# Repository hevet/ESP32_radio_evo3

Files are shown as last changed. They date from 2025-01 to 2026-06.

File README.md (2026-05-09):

# ESP32 Web Radio Evo3 (Evolution 3)

<p align="center">
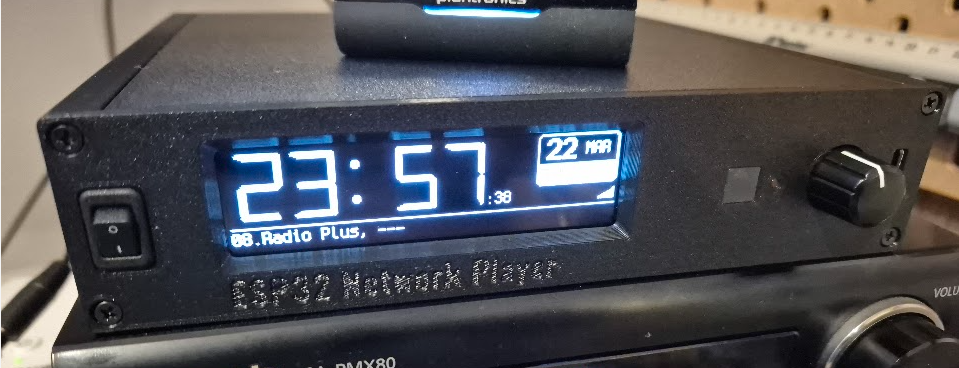
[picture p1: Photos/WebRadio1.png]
ESP32 Radio
  
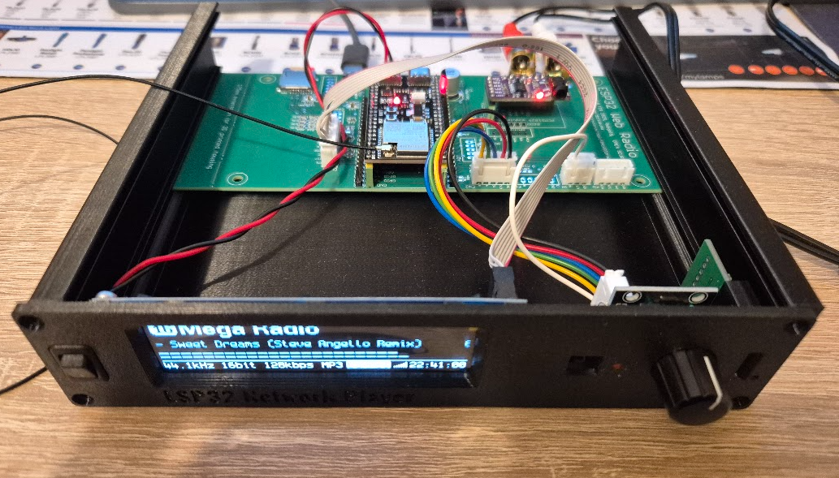
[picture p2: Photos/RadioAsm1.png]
ESP32 Radio
  
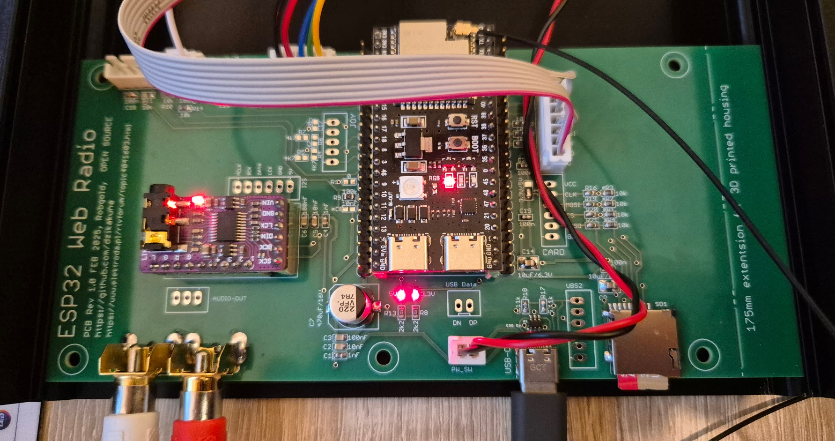
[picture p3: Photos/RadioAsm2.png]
ESP32 Radio
          
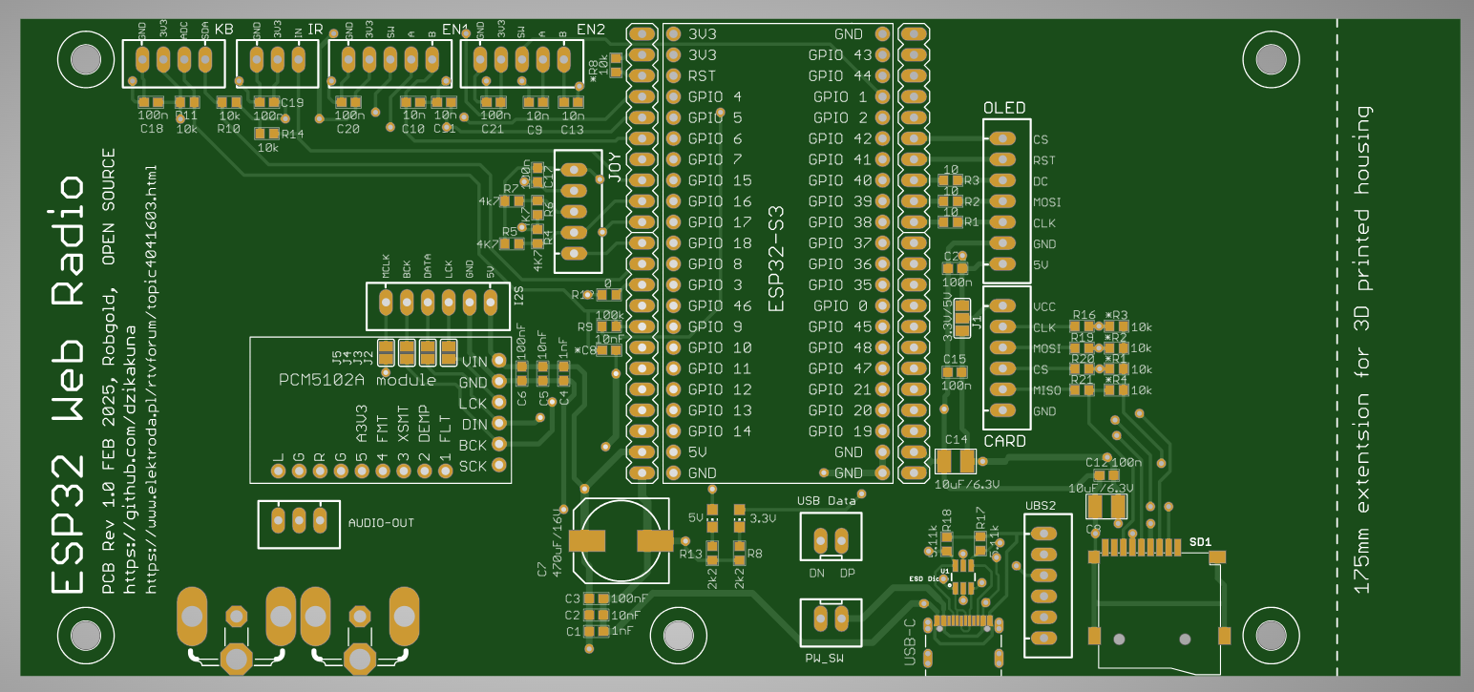
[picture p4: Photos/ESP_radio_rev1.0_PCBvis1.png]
ESP32 Radio
  
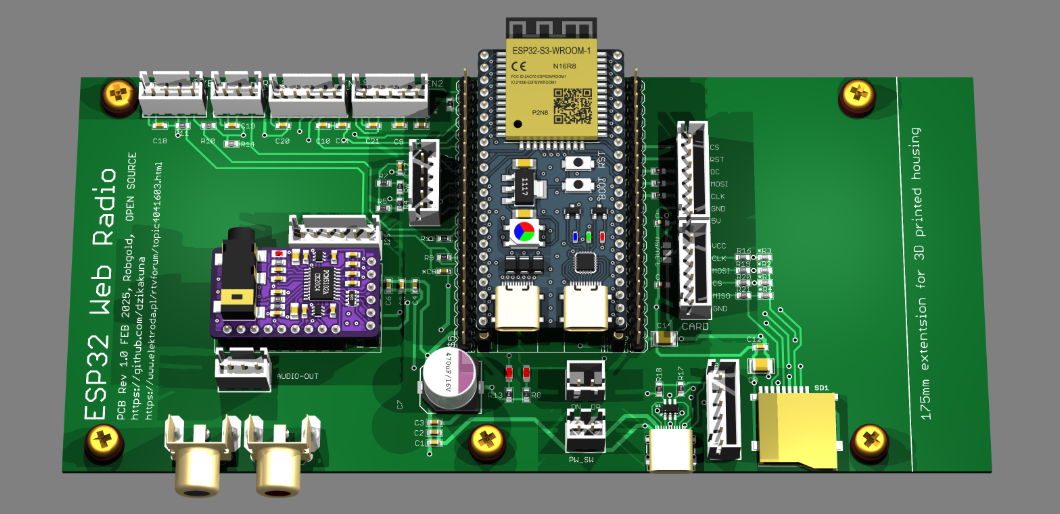
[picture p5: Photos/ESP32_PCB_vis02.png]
  
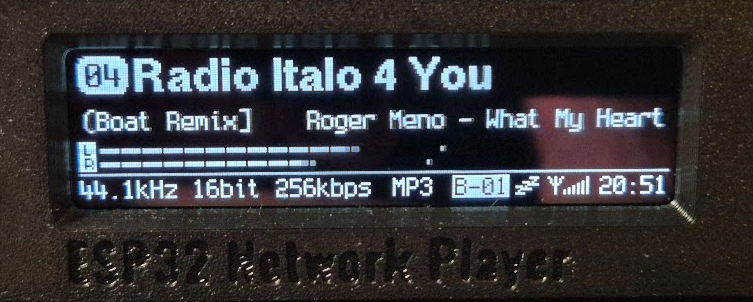
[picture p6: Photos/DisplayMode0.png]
  
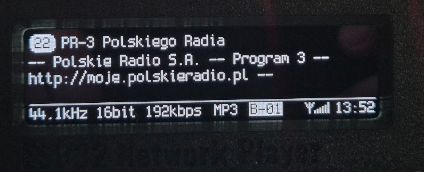
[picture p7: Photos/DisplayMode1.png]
  
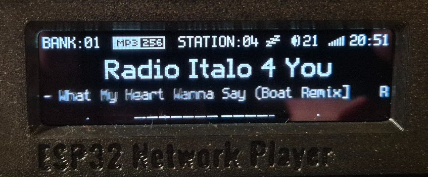
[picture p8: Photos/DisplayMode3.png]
  
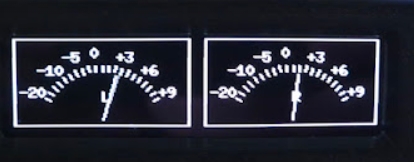
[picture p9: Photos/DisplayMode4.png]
  
</p>

## Overview
This is project of Internet Radio Streamer called "Evo". Hardware was buid using EPS32-S3 and DAC codec PCM5102A. Construction allows to listen varius music station from all around the world.
Working properly with streams coded in MP3, AAC, VORBIS and FLAC up to 2000kbit! Support all operations like volume control, stations changes, memory bank change, power on/off on single rotary 
encoder. Support infrared remote controls working on NEC standars (38kHz) and full control over web page and Android APP.

Many people is mixing wiht others (yoRadio) - Evo is NOT based on yoRadio. Evo Radio streamer was developed entirely in Poland.

Functions:
- Internet radio stream station from bank files (can be stored on SD card/internal LittleFS or downloaded from GitHub)
- I2S simple PCM5102A decoder support
- Full web server integrated for controling from desktop computer or mobile phone
- OLED Display SSD1322, SH1122 (256px x 64px)
- Single rotary encoder operations 
- OTA updates directlly from web page
- SD card /LittleFS content review/upload/download/delete by web page
- VUmeters add as some visualization on OLED
- 16 Banks with 99 station per each Bank support
- Polish fonts add for coorrect display station strings
- 3-point Equalizer
- ADC resistance keyboard support for easy inegration in FM converted tuners
- Power on/off from remote controller
- Sleep timer

## FLAC stations
<p>Smoothjazz.com.pl 16bit 1Mbps and AIDA Radio 24bit 2Mpbs!
<br>
ESP32 Radio
ESP32 Radio
<p>

## Display Modes
ESP32 Radio
ESP32 Radio
ESP32 Radio
ESP32 Radio
ESP32 Radio
ESP32 Radio

## Hardware
- ESP32-S3 dev. module with internal antena or external antena connector
- 256x64 OLED display based on SSD1322 or SH1122 driver IC
- 1x Rotary encoder
- IR 38KHz receiver (Vishay TSOP2238)
- PCB design stored in repository
- Housing avalivle as ready to print STL files
- SD or micro SD card reader (optional)
 
## Software
Project was coded in Arduino but ready main.cpp for Platformio files avalable and also tested

How to compile (Arduino):
- Install fresh Arduino (currently 2.3.6)
- After instalation add ESP32 board package by Espressif (this operation will take some time)
- Install bellow libs inside Arduino (library manager): 
  ESP32-audioI2S, 
  ezButton, 
  U8g2, 
  WiFiManager

Proper version of all libs are placed on top of source code ino file
For Platformio look into src folder -> Platformio folder and Platformio.ini file.

## Software Dependencies
[ESP Espressif 3.3.7 libs]

[3rd-party libs]
- ESP32-audioI2S-master 3.4.4
- U8g2 2.36.5
- ezButton 1.0.4
- WiFiManager 2.0.17
- ESP Async WebServer 3.10.0
- Async TCP 3.4.10

## Web server
Radio has buit in small web server with simple webpage for list stations, bank select, volume control and access to settings menu
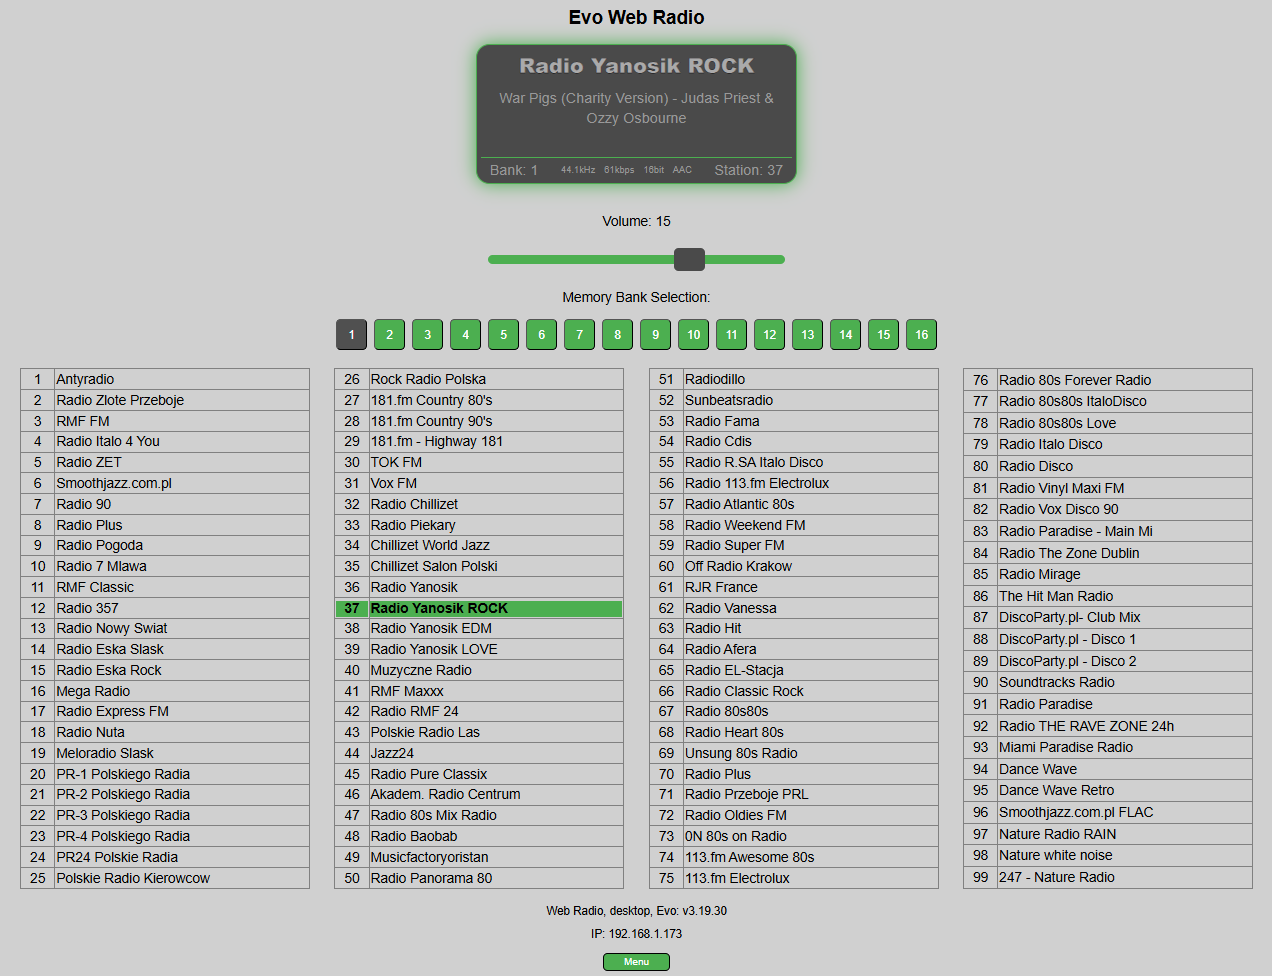
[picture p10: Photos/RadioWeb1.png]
ESP32 Radio


## Radio Browser
The built-in Radio Browser search page allows you to search for various radio stations around the world, and play or test them instantly on Evo Radio.
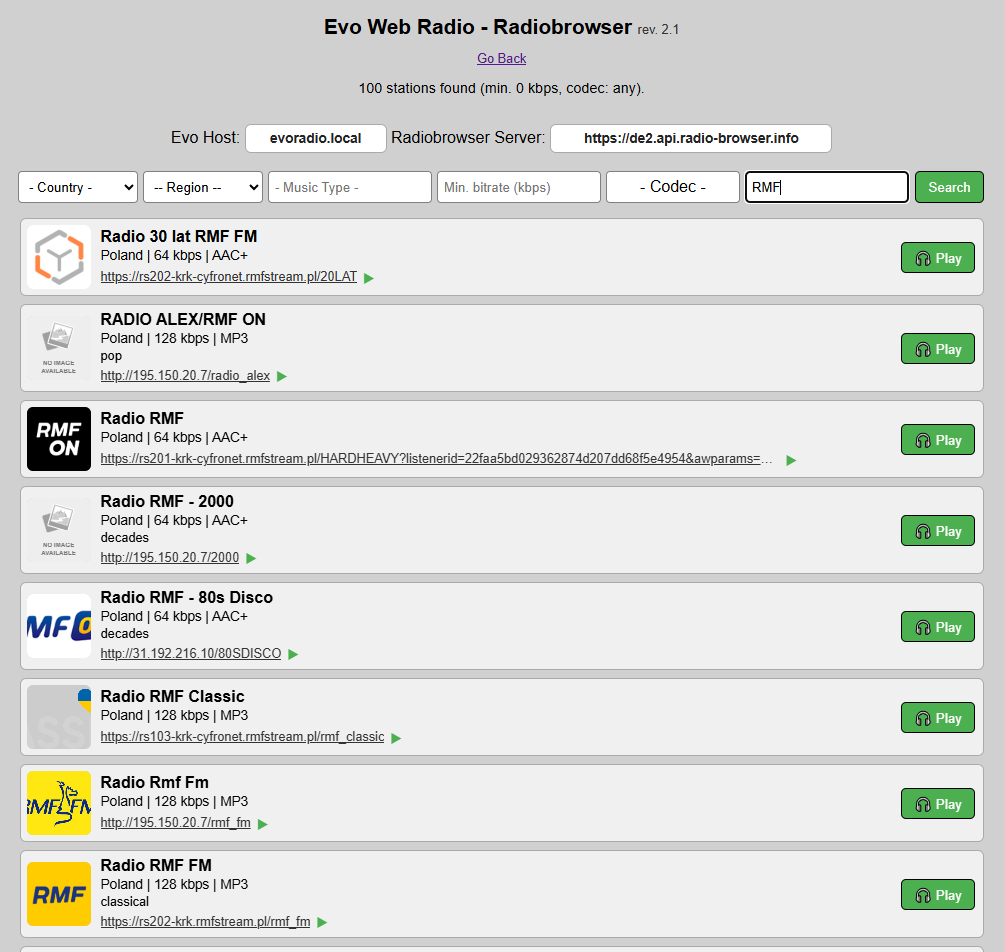
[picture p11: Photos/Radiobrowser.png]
Evo Internet Radio - Radio Browser


## Android APK
There is small Android APK wirtten for this project giving possibily to direct control Evo radio from mobile phone.
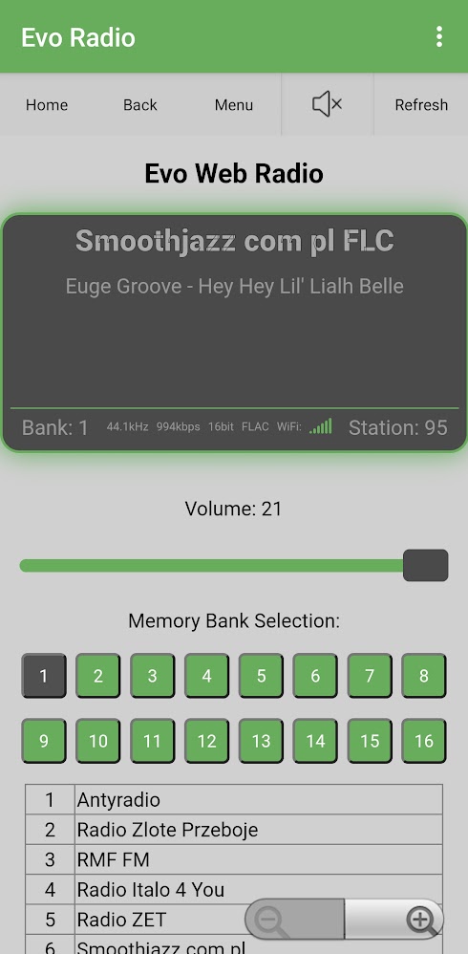
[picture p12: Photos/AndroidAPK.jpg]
Evo Internet Radio - Radio Android APK


There is a pre-coded remote controller RC-406 (Kenwood clone). You can change the settings via a simple web interface or by editing the remote.txt file stored in memory (SD card or internal flash).
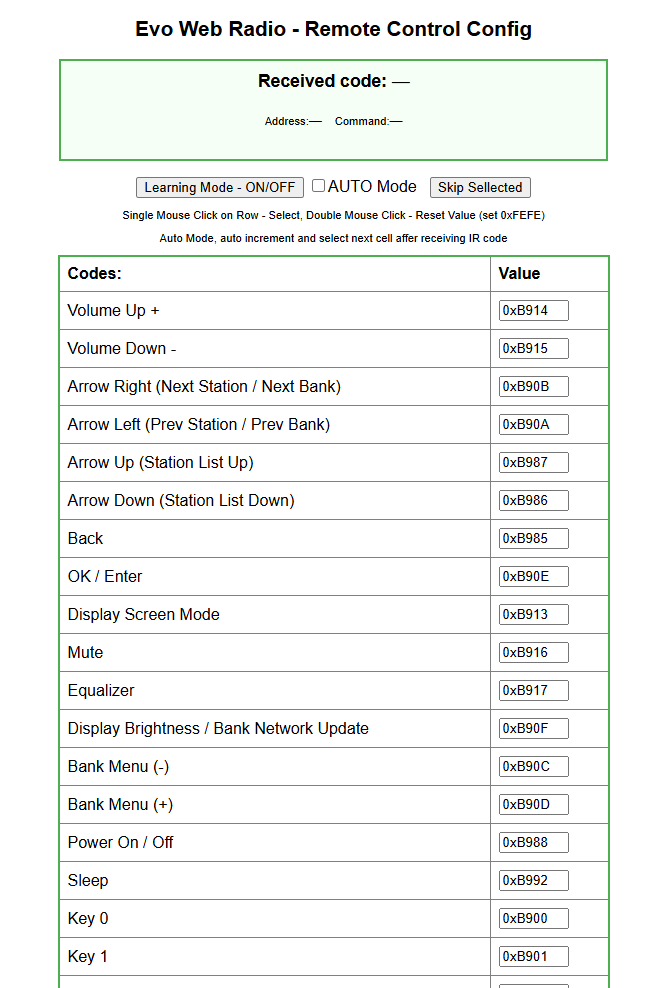
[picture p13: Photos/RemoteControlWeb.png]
Evo Internet Radio - Remote config over web

Key mapping:
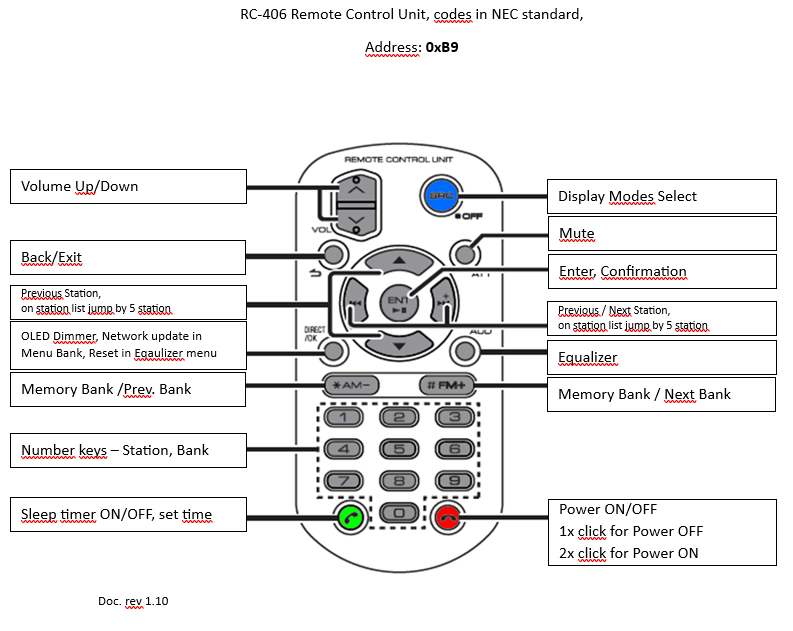
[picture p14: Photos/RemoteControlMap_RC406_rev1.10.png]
Evo Internet Radio - Remote config


## Usage
Minimum radio can be build only with two compoents - ESP32-S3 dev. module and PCM5102A. In this configartion last station, memory bank number and volume will be stored in EEPROM. Control is possible via web page or IR remote control RC-406.
For full experience connect encoder, IR receiver.

NEC standard codes for remote controler are stored in "remote.txt" file. You can learn your IR remote by webpage. 

### Radio Station URLs
The radio streams URL addresses are defined in banks files, each bank is downloaded at first run and stored on SD card as separate txt file: Bank01.txt, Bank02.txt etc.
Each of banks can store 99 station. You can modify the station by changing the URLs in the code. Bank files are stored here:

STATIONS_URL1 "https://raw.githubusercontent.com/dzikakuna/ESP32_radio_streams/main/bank01.txt"
STATIONS_URL2 "https://raw.githubusercontent.com/dzikakuna/ESP32_radio_streams/main/bank02.txt"
STATIONS_URL3 "https://raw.githubusercontent.com/dzikakuna/ESP32_radio_streams/main/bank03.txt"
...
STATIONS_URL16 "https://raw.githubusercontent.com/dzikakuna/ESP32_radio_streams/main/bank16.txt"

## License
This project is open-source and licensed under the [MIT License](https://opensource.org/licenses/MIT). 
Feel free to contribute and improve the code.

MIT License
Copyright (c) 2025 [Grzegorz / Dzikakuna / Robgold ]

Permission is hereby granted, free of charge, to any person obtaining a copy of this software and associated documentation files (the "Software"), to deal in the Software without restriction, including without limitation the rights to use, copy, modify, merge, publish, distribute, sublicense, and/or sell copies of the Software, and to permit persons to whom the Software is furnished to do so, subject to the following conditions:
The above copyright notice and this permission notice shall be included in all copies or substantial portions of the Software.
THE SOFTWARE IS PROVIDED "AS IS", WITHOUT WARRANTY OF ANY KIND, EXPRESS OR IMPLIED, INCLUDING BUT NOT LIMITED TO THE WARRANTIES OF MERCHANTABILITY, FITNESS FOR A PARTICULAR PURPOSE AND NONINFRINGEMENT. IN NO EVENT SHALL THE AUTHORS OR COPYRIGHT HOLDERS BE LIABLE FOR ANY CLAIM, DAMAGES OR OTHER LIABILITY, WHETHER IN AN ACTION OF CONTRACT, TORT OR OTHERWISE, ARISING FROM, OUT OF OR IN CONNECTION WITH THE SOFTWARE OR THE USE OR OTHER DEALINGS IN THE SOFTWARE.

## Others
- This project was inspired by https://github.com/sarunia/ESP32_radio_player_v2
- More informations you can read here: https://www.elektroda.pl/rtvforum/topic4041603.html

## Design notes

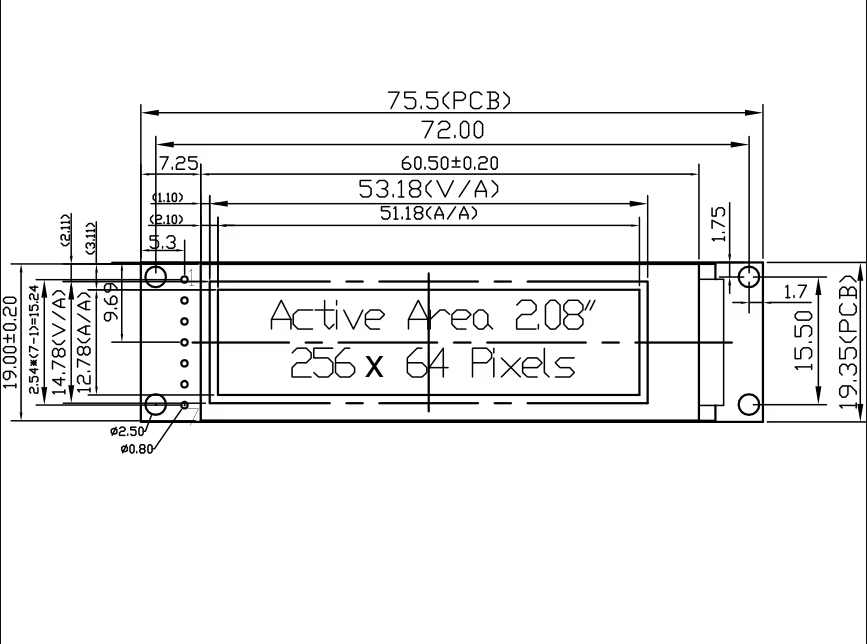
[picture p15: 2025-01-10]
Hardware/Datasheets/2.08 SH1122 OLED display/208-OLED dimensions.png

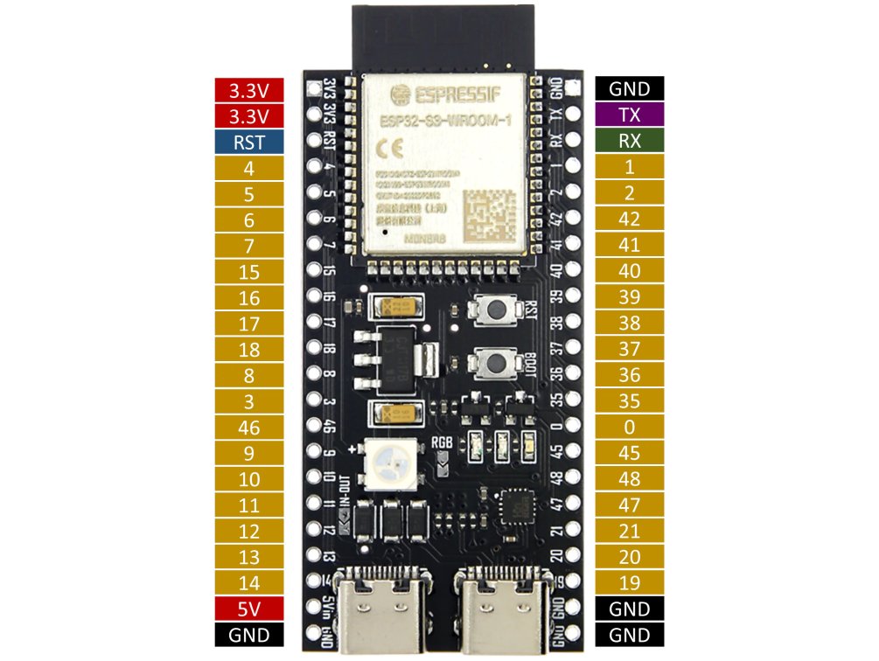
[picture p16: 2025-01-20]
Hardware/Datasheets/ESP/esp32-s3 usbc pinout.jpg

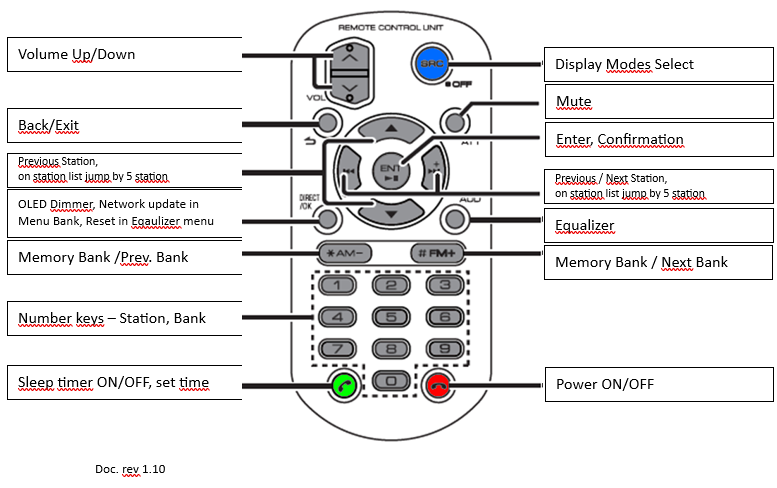
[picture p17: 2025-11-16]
Hardware/RemoteControlMap_RC406_rev1.10.png

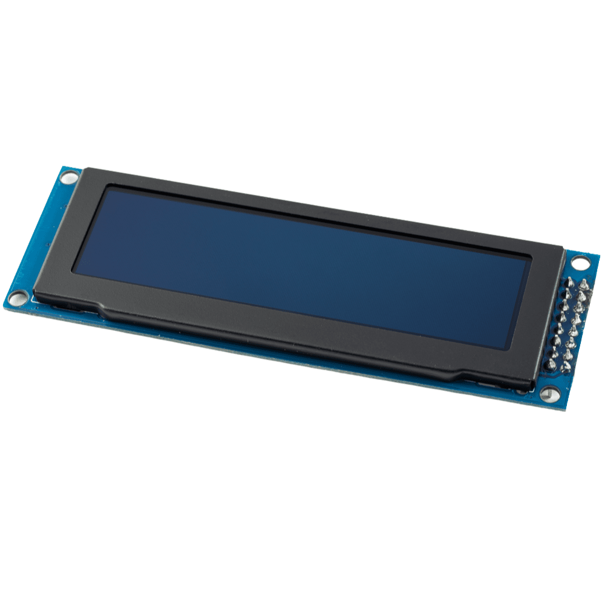
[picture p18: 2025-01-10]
Hardware/Datasheets/3.12 SSD1322 OLED display/312-OLED module photo.png

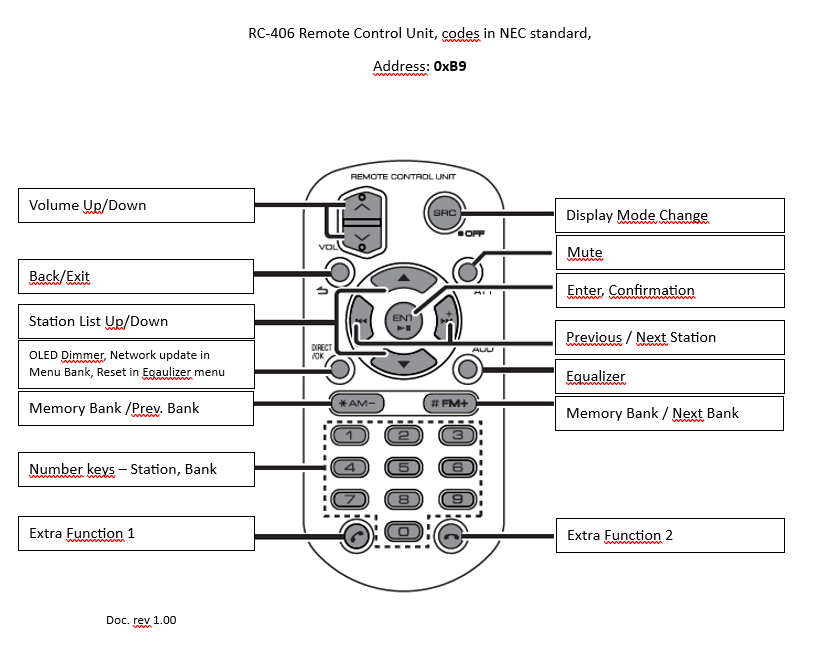
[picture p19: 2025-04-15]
Hardware/RemoteControlMap_RC406_rev1.00.png

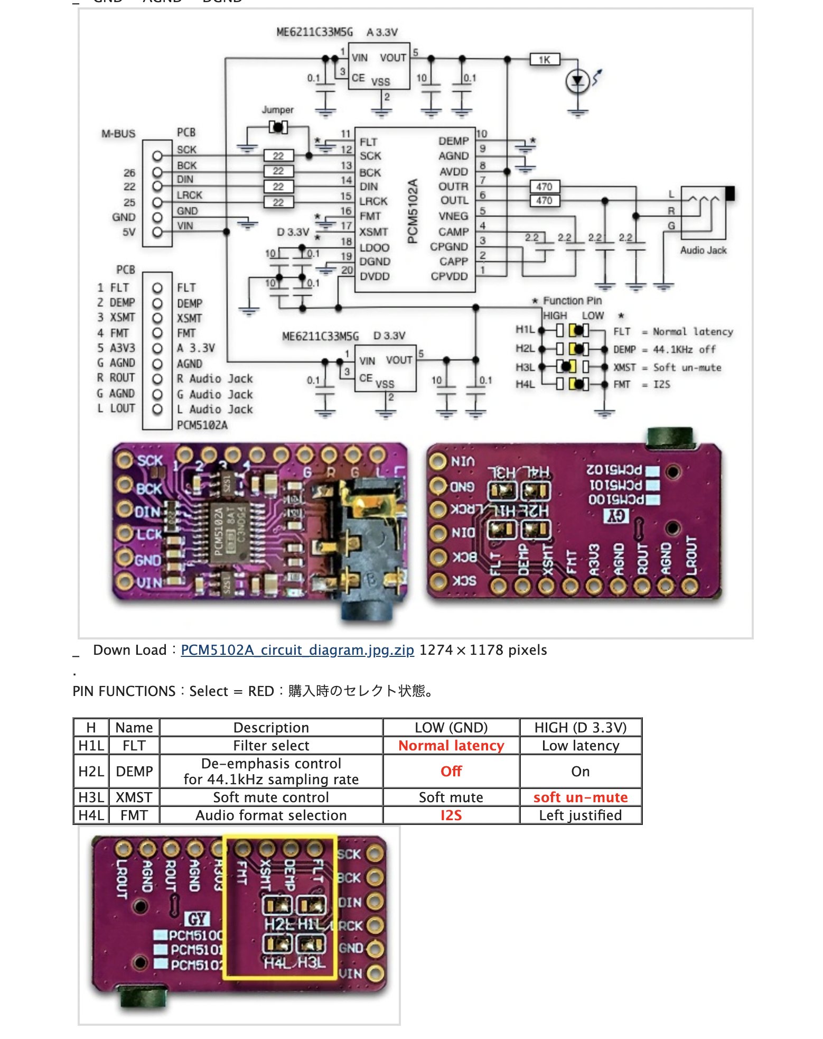
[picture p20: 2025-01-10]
Hardware/Datasheets/PCM5102/pcm5102 jumpers.jpg

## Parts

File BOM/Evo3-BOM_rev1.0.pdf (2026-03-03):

# ESP32 Radio Evo3 - BOM

Designator | Pcs | Value | Device | Package | Description | Link
J1, J2, J3, J4, J5 | 5 | JMP | Jumper | | SMD solder JUMPER
R12 | 1 | 0 | Resistor | 603 | RESISTOR
R1, R2, R3, R16, R19, R20, R21 | 7 | 10 | Resistor | 603 | RESISTOR
R8, R13 | 2 | 2k2 | Resistor | 603 | RESISTOR
R4, R5, R6. R7 | 4 | 4K7 | Resistor | 603 | RESISTOR
*R1, *R2, *R3, *R4, *R8, R10, R11, R14 | 8 | 10k | Resistor | 603 | RESISTOR
R17, R18 | 2 | 5.11k | Resistor | 603 | RESISTOR
R9 | 1 | 100k | Resistor | 603 | RESISTOR
C1, C4 | 2 | 1nF | Capacitor | 603 | CAPACITOR
C2, C5, C9,*C8, C10, C11, C13 | 7 | 10nF | Capacitor | 603 | CAPACITOR
C3, C6, C12, C15, C17, C18, C19, C20, C21, C22 | 10 | 100nF | Capacitor | 603 | CAPACITOR
C8, C14 | | 10uF/6.3V | C-EUC1210 | C1210 | CAPACITOR | https://www.tme.eu/pl/details/0805b106k100ct/kondensatory-mlcc-smd/walsin/https://www.tme.eu/pl/details/cl31b106kahnnne/kondensatory-mlcc-smd/samsung/
C7 | | 470uF/16V | CPOL-EU150CLZ-1010 | 150CLZ-1010 | POLARIZED CAPACITOR | https://www.tme.eu/pl/details/zsc00ag4711carl/kondensatory-elektrolityczne-smd/vishay/
D1, D2 | 2 | 5V | LED | 805 | LED | KPG-1608SURKC-T, KPT-1608SURCK
U1 | 1 | ESD Diode | | SOT-23-6 | | https://www.tme.eu/pl/details/usblc6-2sc6/diody-zabezpieczajace-drabinki/stmicroelectronics/
L-OUT, R-OUT | 2 | TOBU3 | TOBU3 | TOBU3 | Audio Cinch Connector | https://www.tme.eu/pl/details/cc-132-b_1/zlacza-rca-cinch/ninigi/https://www.tme.eu/pl/details/cc-132-r_1/zlacza-rca-cinch/ninigi/
MA10-1 | 2 | MA10-1 | Goldpin 10 pin | MA10-1 | PIN HEADER
MA12-1 | 2 | MA12-1 | Goldpin 12 pin | MA12-1 | PIN HEADER
USB, UBS2, PW_SW | 3 | JST | JST XH-02 | JST-XH-06-PACKAGE | JST XH Series Connector
IR, AUDIO-OUT | 2 | JST | JST-XH-03 | JST-XH-03-PACKAGE | JST XH Series Connector
KB | 1 | JST | JST-XH-04 | JST-XH-04-PACKAGE | JST XH Series Connector
JOY, EN1, EN2 | 3 | JST | JST-XH-05 | JST-XH-05-PACKAGE | JST XH Series Connector
CARD, I2S | 2 | JST | JST-XH-06 | JST-XH-06-PACKAGE | JST XH Series Connector
OLED | 1 | JST | JST-XH-07 | JST-XH-07-PACKAGE | JST XH Series Connector
SD1 | 1 | TF-SOCKET | TF-HOLDER | TF-PULL | TF / Micro SD socket is PUSH-PUSH type,
USB-C | 1 | USB | USB4105-GF-A-120, 12 pin | GFT | CONNECTOR
M1 | 1 | ESP32-S3-USBC | ESP32-S3-USBC | ESP32-S3-USBC | ESP32-S3 16N8 | https://sklep.msalamon.pl/produkt/plytka-esp32-esp32-s3-devkit-wifi-ble-5-0/
M2 | 1 | I2S_PCM_51XX_SOUNDCARD PCM Module | | | I2S_PCM_51XX_SOUNDCARD MODULE | https://sklep.msalamon.pl/produkt/modul-dekodera-dac-pcm5102a-i2s/
OLED Display | | | | | OLED, 3.12inch, SSD1322 or 2.08-SH1122 | https://sklep.msalamon.pl/produkt/wyswietlacz-oled-312-256x64px-zolty/https://sklep.msalamon.pl/produkt/wyswietlacz-oled-208%e2%80%b3-256x64px-spi-bialy/
Encoders | | | | | Toraty encoder | https://sklep.msalamon.pl/produkt/modul-enkodera-z-przyciskiem/
SD Card Reader (external) | | | | | | https://sklep.msalamon.pl/produkt/czytnik-kart-pamieci-microsd-spi-sdio/
IR Receiver | | TSOP2238 | | | Vishay, 38kHz; 2,5÷5,5V; 90° | https://www.tme.eu/pl/katalog/?queryPhrase=TSOP2238

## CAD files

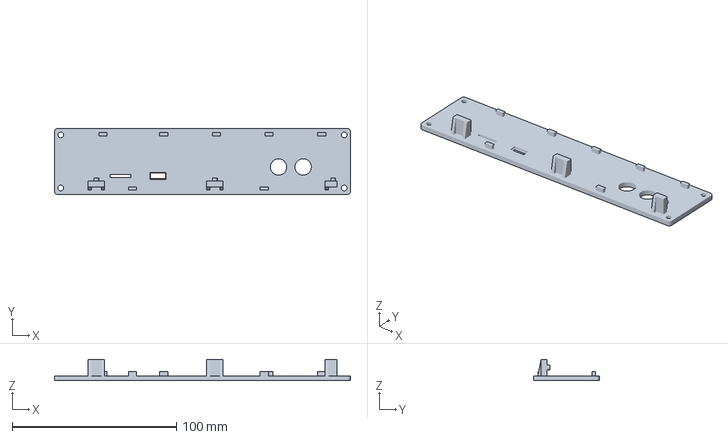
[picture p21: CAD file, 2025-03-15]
Hardware/Housing/3D printed variant/Back/Back_panel_v1.05c-long.3mf
180.0 x 40.0 x 13.0 mm

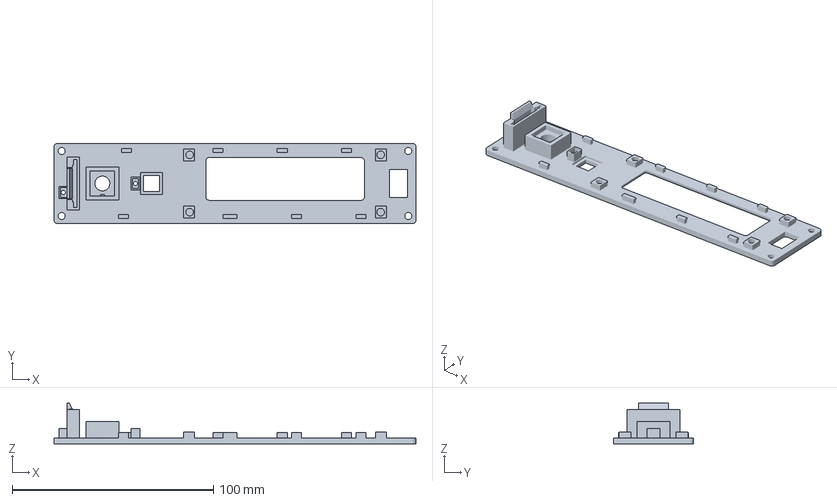
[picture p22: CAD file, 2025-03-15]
Hardware/Housing/3D printed variant/Front/Front panel v1.25sq-long.mf.3mf
180.0 x 40.0 x 20.2 mm

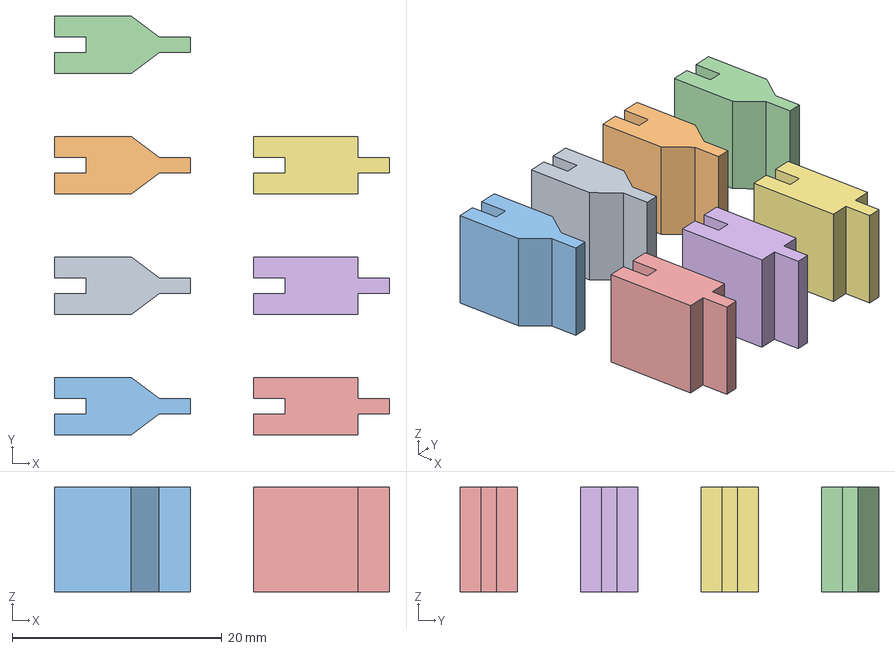
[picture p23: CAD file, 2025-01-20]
Hardware/Housing/3D printed variant/PCB_extender150-2-160mm_v2.3mf
32.0 x 40.0 x 10.0 mm
PCB_extender150-2-160mm.stl
PCB_extender150-2-160mm_v2.stl

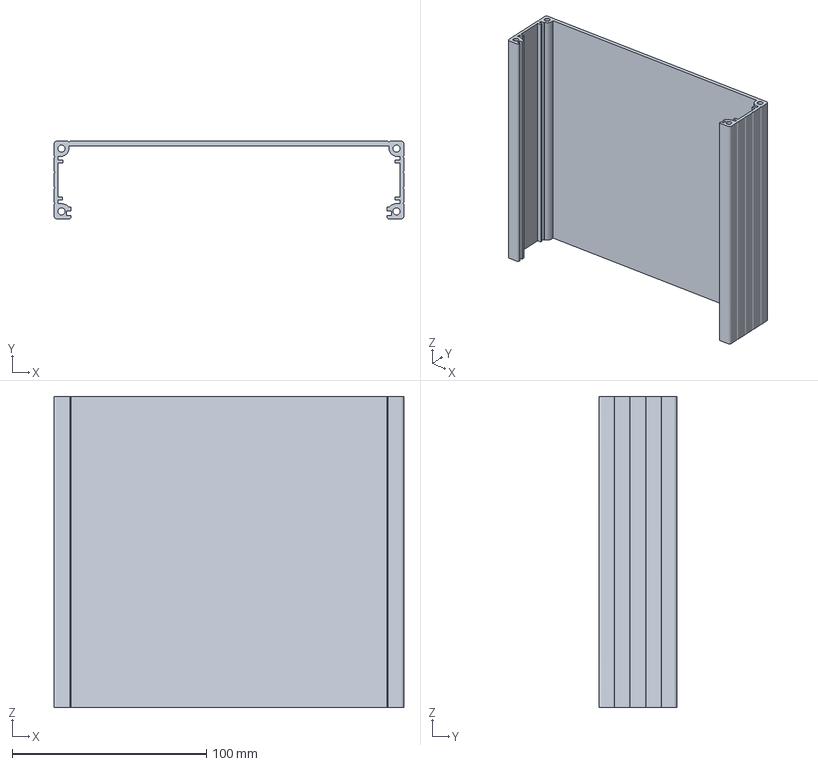
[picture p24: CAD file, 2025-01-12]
Hardware/Housing/3D printed variant/Profil/Profil_v1.8_long.3mf
180.0 x 40.0 x 160.0 mm

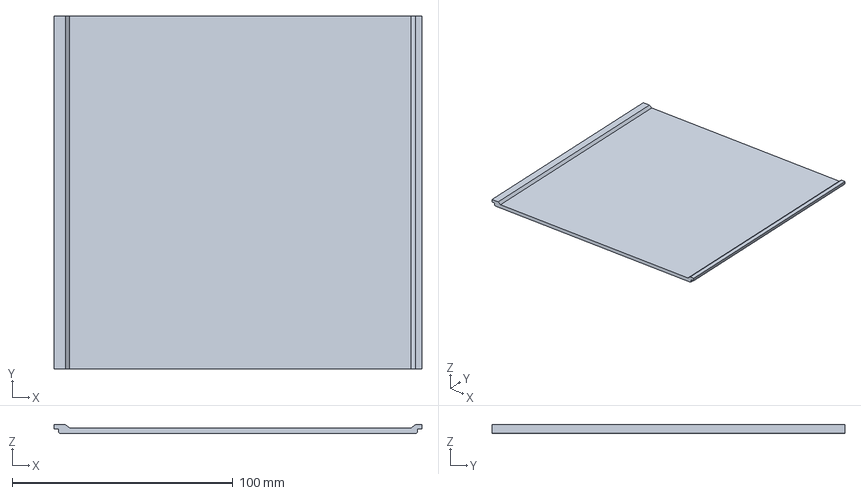
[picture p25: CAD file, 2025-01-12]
Hardware/Housing/3D printed variant/TopCover/Cover_v1_profil_1.8_long.3mf
166.7 x 160.0 x 3.95 mm

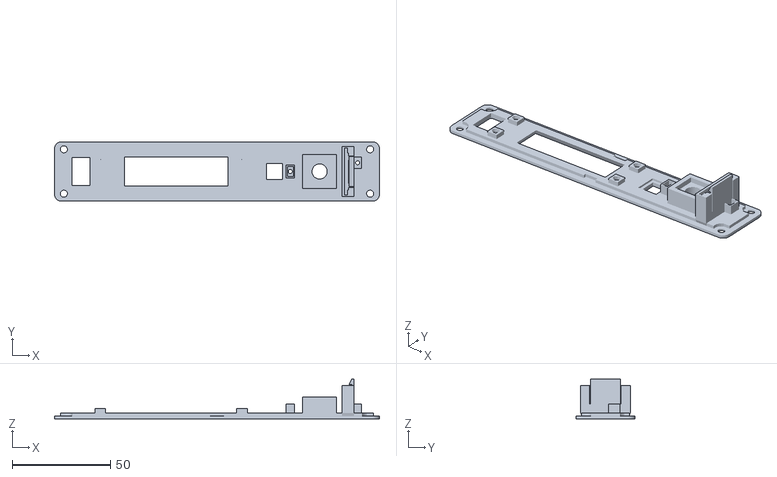
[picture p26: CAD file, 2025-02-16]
Hardware/Housing/Hammond_1455R1601BK/1455_Front_1.0c.stl
165.0 x 30.1 x 20.2

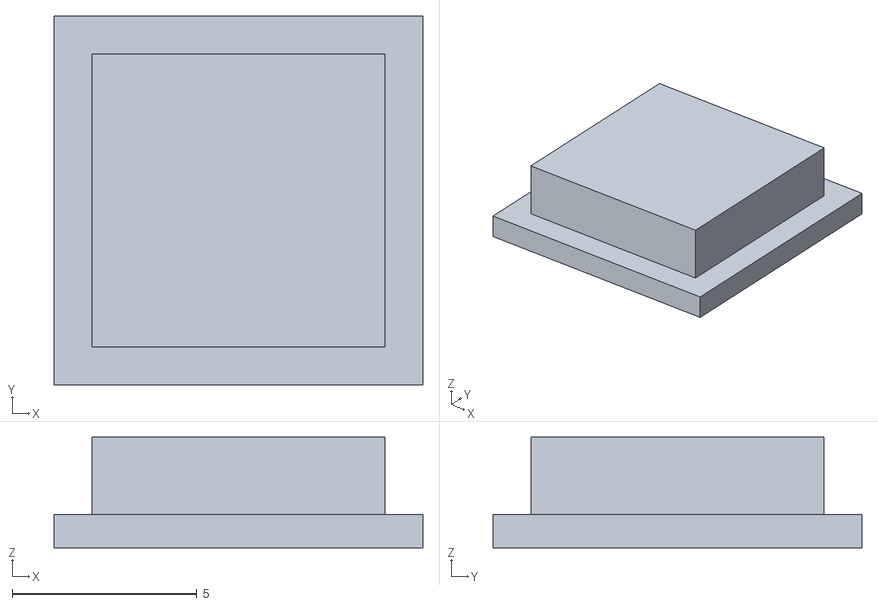
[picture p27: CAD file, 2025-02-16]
Hardware/Housing/3D printed variant/Front/IR_cap_v2.stl
10.0 x 10.0 x 3.00

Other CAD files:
Hardware/Housing/3D printed variant/Front/Front panel v1.25sq-long.stl
Hardware/Housing/3D printed variant/Back/Back_panel_v1.05c-long.stl
Hardware/Housing/3D printed variant/Profil/Profil_v1.8_long.stl
Hardware/Housing/3D printed variant/TopCover/Cover_v1_profil_1.8_long.stl

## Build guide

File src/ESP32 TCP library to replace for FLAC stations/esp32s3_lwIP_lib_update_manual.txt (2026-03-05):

This libs change throughput of WiFi network on ESP32 so FLAC stream work smoothly upt o 2500kbps.

Manual based on core 3.3.3, for higer version jsut change "idf-release_v5.4-xyz" to proper folder

Replace file in location:
C:\Users\YOUR USER NAME\AppData\Local\Arduino15\packages\esp32\tools\esp32-arduino-libs\idf-release_v5.4-xyz\esp32s3

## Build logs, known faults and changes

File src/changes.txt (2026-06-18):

Changes tracking file for ESP32 -  "Evo Internet Radio" - Evo_V3

3.20.14
ESP32 Core: 3.3.8
"FLAC" libs: recompiled on ESP-IDF 5.5.4
Arduino 2.3.6

- volume range change ( 0- 21/42) - 0 set MUTE flag
- Auto RTC sync every 3h in sleep mode
- TAS configuration corrected
- VU meter, mode 3 corrected right value (bug correction)
- station list - corrected proper set cursor to current station from IR remote
- settings add, change station from list without confirmation by encoder button
- code corretion when "Play from URL" - now display correct station name
- corrected name for "Power button" during remote learning process
- code house keeping

3.20.04
ESP32 CORE 3.3.7 + own FLAC libs
AsyncTCP 3.4.10
Async WebServer 3.10.0
Audio i2c lib 3.4.4x

- new range of Equalizer settings (-12dB - +12dB) according to new audio lib
- Balance option add in equalizer menu (-16dB - +16dB)
- WiFi signal indicatior add to Web Page
- VU clippin9g issue with rollback eliminated
- IR Remote web learing interface
- ADC Keyboard keys extended by adding Arrow Keys, Preset On/Off key
- Rename of ADC Key signals
- Standby LED now is also status LED during radio startup (timer4 added in code)
- Preset option add for quick access to station 1-10 on each Bank
- New Analog VU meter as Screen mode 4
- New Digital VU meter as Screen mode 5
- Support TAS5805 integration (experimental)
- Add support for Autostorage with SD card / SPIFFS / LittleFS

--------------------------------
3.19.70 IS THE LAST VERSION COMPATIBLE WITH AUDIO LIB "ESP32-audioI2S-master by schreibfaul1" - 3.4.4l 
CoreESP32 3.3.3 used until this revision

3.19.70
- Replace SPIFFS by LittleFS 
- Auto dedection of SD card / Little FS storage - sitll experimental but should work correct
- New bank editor 1.06
- New Radio Browser 2.1 (auto dedect of alive server add)
- Font change for code and bitrate info in mode 3
- WebSocket corrected for better berformance on web page
- New UTF8 coddding for WebSockets 
- Slow logo fade-in effect added
- PowerOff Animation configured via web page
- Corrected station list function, now after clikc or rotate currently played station will be highligted on top
- StatusLED add, now GPIO17 is assigned as IR LED activity, PowerLED-Standby, SD-Card Activity LED
- Communication via RS232 add for future integration
- Corrected systematic RTC error in powerOff mode with clock display

3.19.53
- corrected issue with logo loading when using SPIFFS
- corrected proper back from settings (OLED refresh)
- corrected save station and bank when only bank was changed
- fetchStation function now with redirection option

3.19.52
- add option "Play form URL" in main menu
- add own LOGO at start-up loaded from SD (if exist) - file logo.xbm (256x64)
- recovery mode update, WIFI manager mode
	- auto reset after connection add
	- info "CONNECTED" after proper connection and display assgined by router IP
- Save Always flag add to prevent saving on every change Station No, Bank No., Volume value speciali if we usign SPIFFS
- Extra audio buffer view in VU mode 4
- correction of VU max value to avoid clipping in mode0
- Info about used library revision is now placed inside source code
- [pssibility to use JOY signals for SD Active, SW Power, 

3.19.48
- correct switch off when PowerClock flag is set to 0
- corrected WS inside html control
- Welcome message now shows SD/SPIFSS and TwoEncoders flags settings

3.19.47

- Storage: Now you can select inside code if you are using SD Card or SPIFFS memory by single line change
- 2nd Encoder add as an option
- Single click powerOff / powerOn by remote control and by click on encoders
- Replace on Config web all Select items by CheckBoxes
- DisplayRadio: Change evt audio refrash action, no scroller function in mode 1 (big clock), just static name of selected station
- Radio TitleName: BOM UTF signs removed (ex. visable on on RadioZET)
- WWW page: Mute indicator add
- BUGs dedected: 
	- Change volume on web page during MUTE was not switching off mute flag
	- Corrected NTP->RTC sync. after power lose

3.19.33
- Corrected reaction on digits keys when playing from URL
- Configuration File: Updated to include reaction after power fail
- Radiobroswer: update web page to autodedect IP/Hostname
- Udpate Info Web Page with documentation links
- New Start Logo with "Evo"

3.19.32
- Power Modes: Full reset functionality added after wake-up; ON/OFF function can be controlled via remote control or encoder switch
- Power Status Control: Reset source dedection add, if there was blackout radio will go to sleep mode
- Sleep Mode: Added with selectable timers of 15, 30, 45, 75, and 90 minutes
- No Network Mode: Added IR control in no network mode, Power OFF and Restart possible
- Configuration File: Updated to include on/off option for the clock in sleep mode on or off
- Full-Screen Clock: Now displayed during sleep mode
- Radio Browser API Integration: Search and play radio stations directly from RadioBrowser servers
- Station Navigation: Using the arrow keys now works in loop mode; reaching the last station (e.g., 99) moves to station 1 automatically

3.19.19
- corrected bitrate dispaly with estiamted bitrate
- in station list menu left and right arrows now increase station count by 5 (speed move on list)
- add remote POWER OFF/ON option puting ESP32 in light sleep mode. Function under rcCmdRed button on remote

3.19.11
- this is copy of version 3.18.21 with support for new audio i2s (3.4.2 and higher) library and ESP32 core (3.2.0)
- support new stream info read
- new function to feed stream data on OLED display
- preparation for increase banks numbers
- code clean

--------------------------------

3.18.21
- THIS IS LAST VERSION WORKING ON OLD AUDIO LIBRARY AND ESP32 CORE 

Arduino IDE 2.3.4

Lib list:
ESP32 3.0.7
AsyncTCP 3.3.6
ESP Asunc WebServer 3.7.2
ESP-audioI2S-master 3.0.13 + recompiled wip, netif
U8g2 2.36.5
WiFiManager 2.0.17
ezButton 1.0.4

changes:
- corrected station list open from remote controler
- station list starting from current playing station
- new OLED mode 3 screen  with centered content and mini VU meters
- new OLED mode 4 with full screen VU meters

3.18.12
- smooth mode of VU meter
- new layout of mode 0
- new layout of station list
- new font for radio station name
- corrected recovery mode response
- web configuration, default values added
- option for read station name direcly from stream -  experimental!

3.18.06
- New VUmeter with 1px increase, L,R letters
- Peak & Hold VUmeter function added

3.18.05
- correction of 1250 to UTF8 function

3.18.04
- correction of 1250 to UTF8 add for station string
- code clean from unused functions
- remove ScrollerFormater function from displayRadio function
- separate ScrollerFormater fucntion add to avoid flickering on station with autoDJ and counter in station string

3.17.99
- bits per sample info add to webpage
- sampling rate info add to webpage
- samplerate info add to webpage
- stream format info add to webpage
- "no audio stream" info add to webpage
- OLED Display Mode button hidden under Web Display BOX - reaction OnClick

3.17.86
- Stationtext as no scrolling text on webpage, just 3 lines
- Recation on volume slider with mouse wheel
- No processor function to parse station name, station text, volume value. Now it worsk on WebSockets.
- Config option for volume rage 1-21 or 1-42 now change is executed after saving config (no restart required)
- Menu link in style of other buttons

3.17.77
- Add web sockets to web page
- New layout of web page
- Refresh Station String in real time on web page
- Refresh Volume over ws in real time on web page
- Bank Editor 1.05 
- Config option for volume rage 1-21 or 1-42
- mDNS add, radio hostname: http://esp32radio.local

3.17
- OTA Update directly from web page
- SD card content browser over the web page (view, delete, edit)
- IR codes stored on SD card in remote.txt file
- Voice prompt of the time (PL and EN function avaliable)
- Sub-revisioning system add (3.17.xx)
- ADC Keyboard config web page added
- OLED Power Save mode added

3.16
- This is first version that can work without SD CARD
- In case of lack of SD card, station number, bank number, volume value are stored in EEPROM
- Recover mode (update, reset bank value, reset station number value)

3.15
- Add 3-point equlizer with values soterd on sd card
- Resistive-matrix keyboard based on single ADC input (ADC1, GPIO 9)
- single rotary encoder operations
- scrolling fucntion for station name if case of no emitted station string value
- WiFi signal level on display
- additional fullscreen clock mode
- Correction of Polish signs inside font
- Scrolling stations nad banks in loop
- Add Vorbis VBR format

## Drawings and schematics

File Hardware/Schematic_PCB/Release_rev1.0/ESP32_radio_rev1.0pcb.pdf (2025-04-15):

# GND ESP³²⁻S³

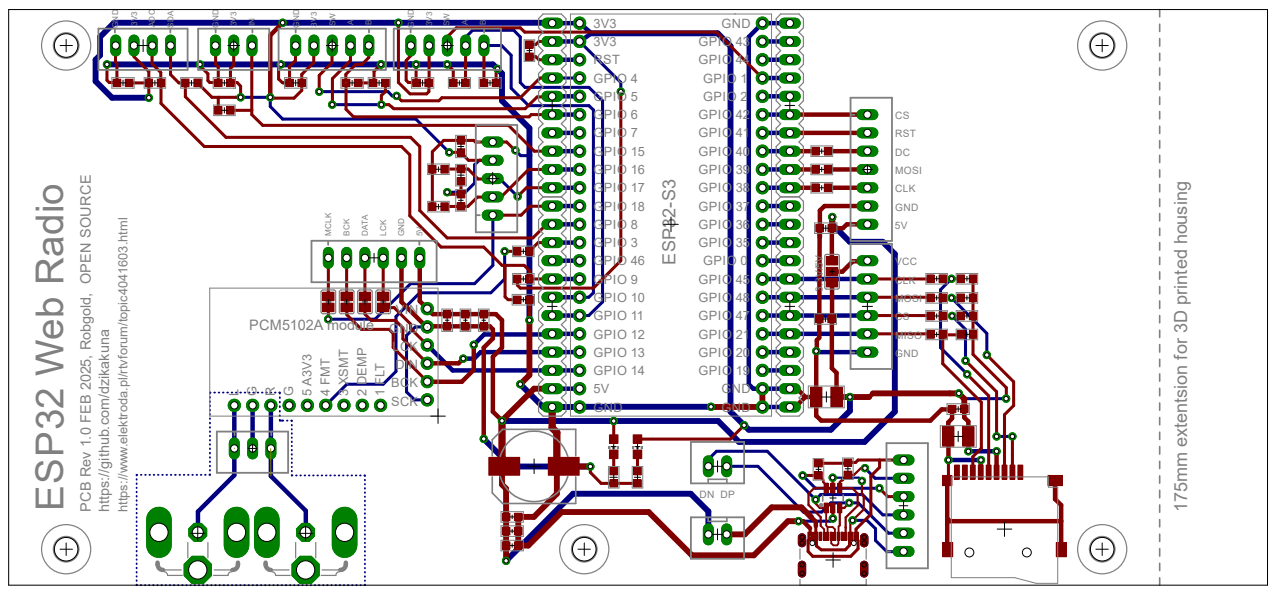
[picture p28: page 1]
GND; CLK; MOSI; RST; MISO; VCC GND; ADC; SDA; SWA; BGND 3V3 SWA; 3V3 3V3 RST GPIO 4 GPIO 5 GPIO 6 GPIO 7 GPIO 15 GPIO 16 GPIO 17 GPIO 18 GPIO 8 GPIO 3 GPIO 46 GPIO 9 GPIO 10 GPIO 11 GPIO 12 GPIO 13 GPIO 14 5V; GPIO 19; GPIO 20; GPIO 21; GPIO 47; GPIO 48; GPIO 45; GPIO 0; GPIO 35; GPIO 36; GPIO 37; GPIO 38; GPIO 39; GPIO 40; GPIO 41; GPIO 42; GPIO 2; GPIO 1; GPIO 44; GPIO 43; SCK; BCK; DIN; LCK; VIN

B 3.3V/5V MCLK BCK DATA LCK GND 5V

ESP32 Web Radio PCB Rev 1.0 FEB 2025, Robgold, OPEN SOURCE https://github.com/dzikakuna https://www.elektroda.pl/rtvforum/topic4041603.html 175mm extentsion for 3D printed housing PCM5102A module

RG5 A3V3 4 FMT 3 XSMT 2 DEMP 1 FLT

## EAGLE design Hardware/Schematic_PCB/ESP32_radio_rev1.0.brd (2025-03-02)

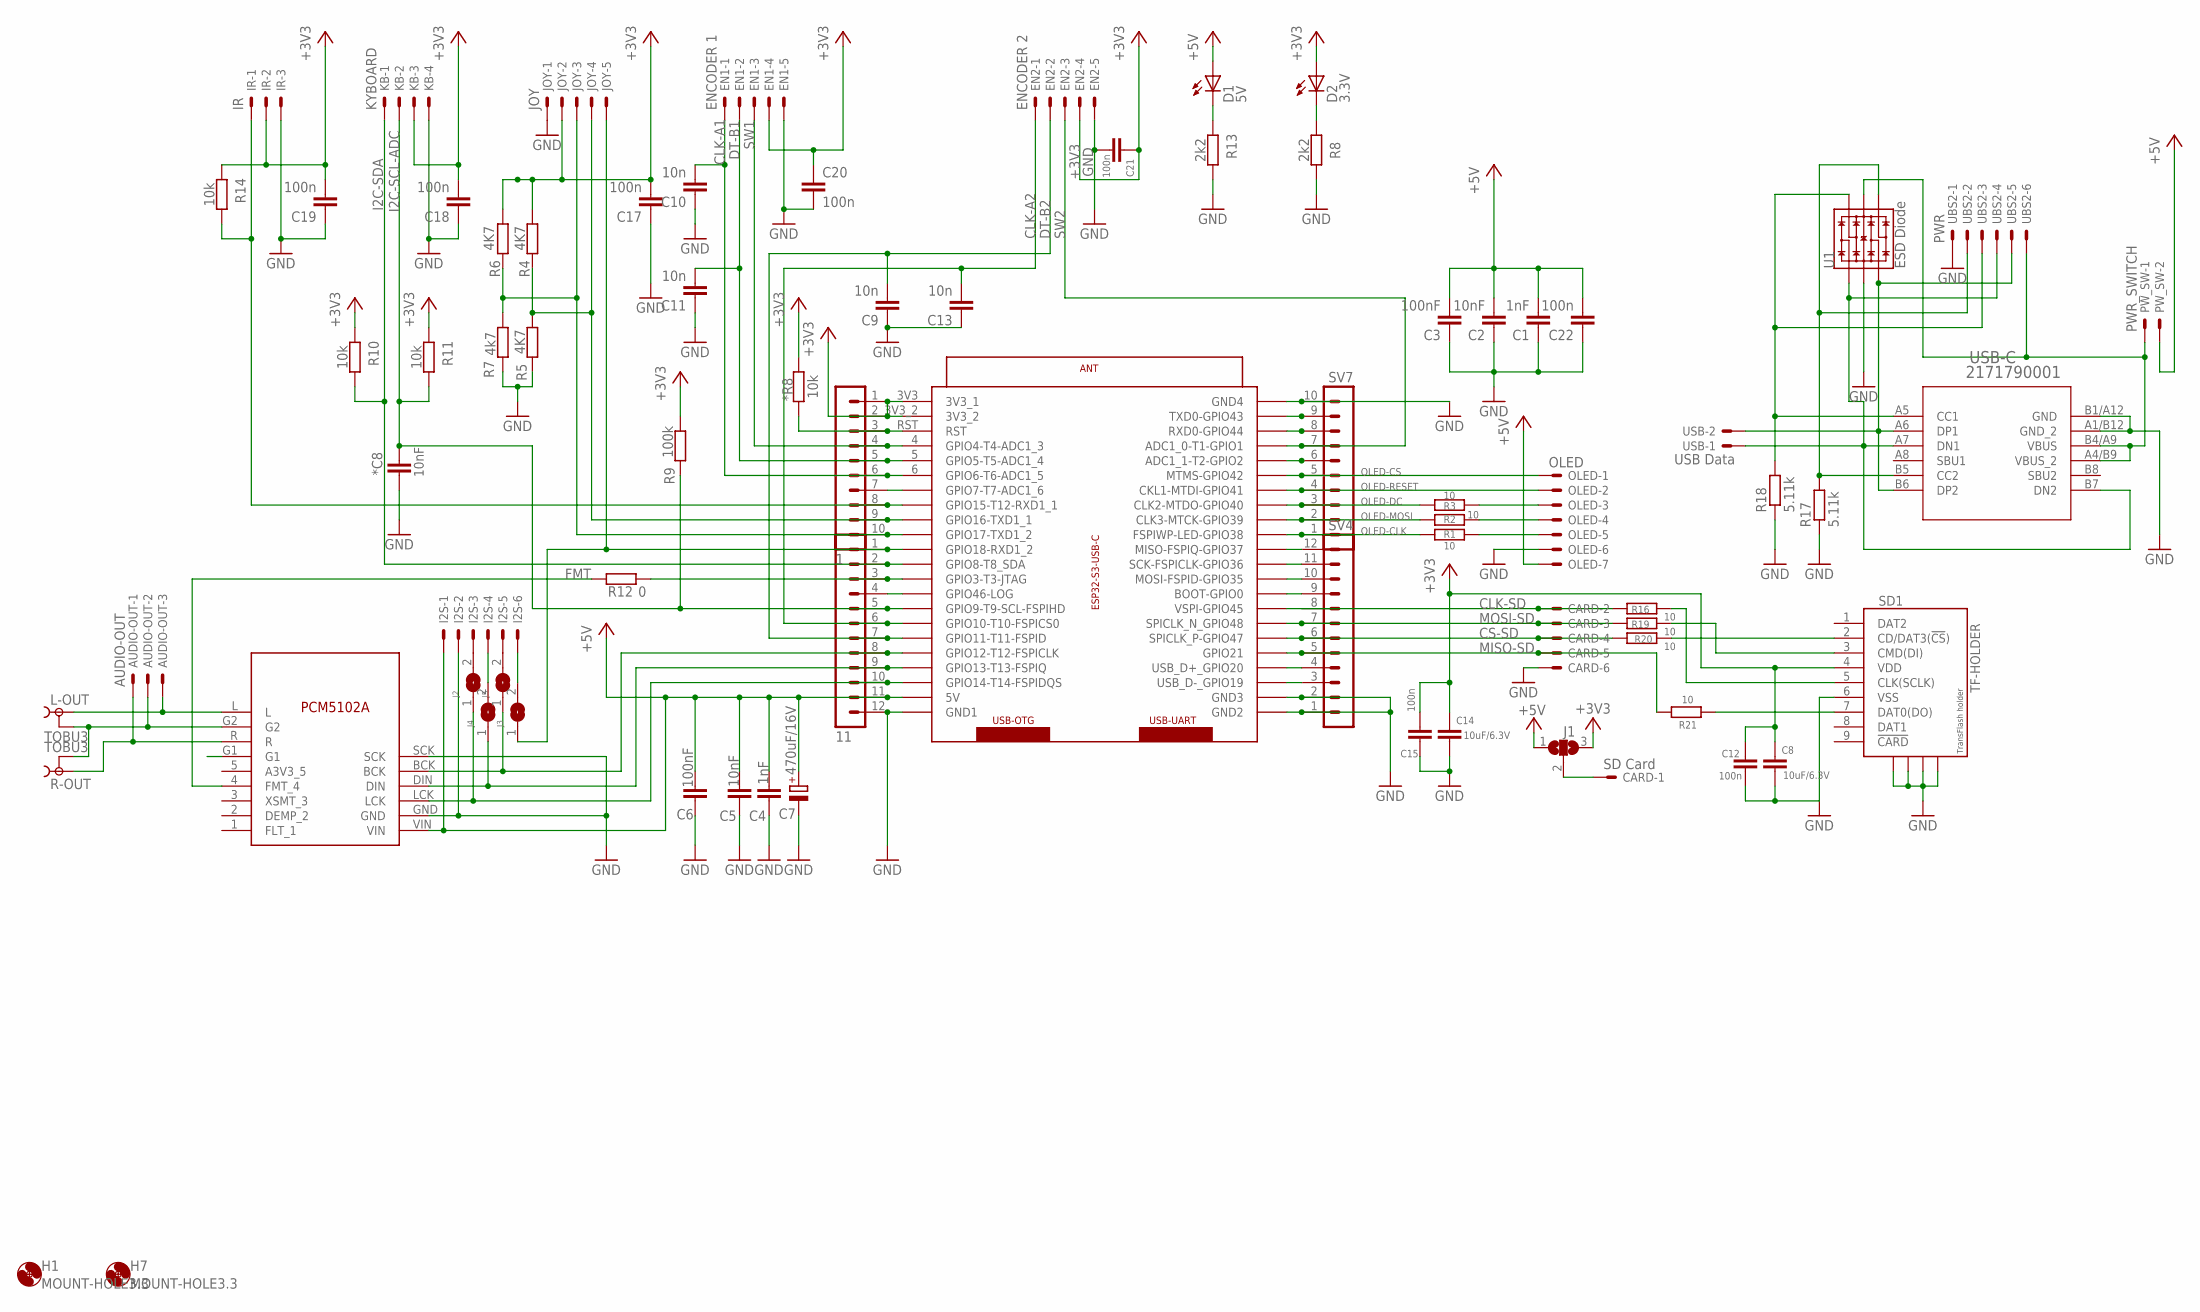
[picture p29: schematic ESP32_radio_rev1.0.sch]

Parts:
1: MA10-1
11: MA12-1
*C8: 10nF; C0603
*R8: 10k; R0603
AUDIO-OUT: AUDIO-OUT; JST-XH-03-PACKAGE-LONG-PAD
C1, C4: 1nF; C0603
C2, C5: 10nF; C0603
C3, C6: 100nF; C0603
C7: 470uF/16V; 150CLZ-1010
C8, C14: 10uF/6.3V; C1210
C9, C10, C11, C13: 10n; C0603
C12, C15, C17, C18, C19, C20, C21, C22: 100n; C0603
CARD: SD Card; JST-XH-06-PACKAGE-LONG-PAD
D1: 5V; CHIP-LED0805
D2: 3.3V; CHIP-LED0805
EN1: ENCODER 1; JST-XH-05-PACKAGE-LONG-PAD
EN2: ENCODER 2; JST-XH-05-PACKAGE-LONG-PAD
H1, H7: MOUNT-HOLE3.3; 3,3
I2S: JST-XH-06-PIN-LONG-PAD; JST-XH-06-PACKAGE-LONG-PAD
IR: IR; JST-XH-03-PACKAGE-LONG-PAD
J1: SJ2W; SJ_2
J2, J3, J4, J5: SJ
JOY: JOY; JST-XH-05-PACKAGE-LONG-PAD
KB: KYBOARD; JST-XH-04-PACKAGE-LONG-PAD
L-OUT: TOBU3
M2: I2S_PCM_51XX_SOUNDCARD; I2S_PCM_5100_SOUNDCARD
OLED: OLED; JST-XH-07-PACKAGE-LONG-PAD
PW_SW: PWR_SWITCH; JST-XH-02-PACKAGE-LONG-PAD
R1, R2, R3, R16, R19, R20, R21: 10; R0603
R4, R5, R6: 4K7; R0603
R7: 4k7; R0603
R8, R13: 2k2; R0603
R9: 100k; R0603
R10, R11, R14: 10k; R0603
R12: 0; R0603
R17, R18: 5.11k; R0603
R-OUT: TOBU3
SD1: TF-HOLDER; TF-PULL
SV4: MA12-1
SV7: MA10-1
U1: ESD Diode; SOT-23-6
U$1: ESP32-S3-USBC
UBS2: PWR; JST-XH-06-PACKAGE-LONG-PAD
USB: USB Data; JST-XH-02-PACKAGE-LONG-PAD
USB-C: 2171790001; 2171790001_MOL

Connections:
5V_USB: PW_SW.1, U1.5 (VCC), UBS2.6, USB-C.A4/B9 (VBUS_2), USB-C.B4/A9 (VBUS)
+3V3: 1.1, 1.2, *R8.1, C8.1, C12.2, C14.1, C15.2, C17.2, C18.2, C19.2, C20.1, C21.1, D2.A, EN1.4, EN2.4, IR.2, J1.3, JOY.2, KB.3, R4.2, R6.2, R9.2, R10.2, R11.2, R14.2, SD1.4 (VDD), U$1.3V3 (3V3_1), U$1.3V3_2
+5V: 11.11, C1.2, C2.2, C3.2, C4.2, C5.2, C6.2, C7.+, C22.2, D1.A, I2S.1, J1.1, M2.VIN, OLED.7, PW_SW.2, U$1.5V
ANALOGGND: AUDIO-OUT.2, L-OUT.2, L-OUT.2@1 (2), L-OUT.2@2 (2), M2.G2, R-OUT.2, R-OUT.2@1 (2), R-OUT.2@2 (2)
CLK-A1: 1.6, C10.2, EN1.1, U$1.6 (GPIO6-T6-ADC1_5)
CLK-A2: 11.6, C13.2, EN2.1, U$1.10 (GPIO10-T10-FSPICS0)
CLK-SD: CARD.2, R16.1, SV4.8, U$1.45 (VSPI-GPIO45)
CS-SD: CARD.4, R20.1, SV4.6, U$1.47 (SPICLK_P-GPIO47)
DT-B1: 1.5, C11.2, EN1.2, U$1.5 (GPIO5-T5-ADC1_4)
DT-B2: 11.7, C9.2, EN2.2, U$1.11 (GPIO11-T11-FSPID)
FMT: M2.4 (FMT_4), R12.2
FMT1: 11.4, U$1.46 (GPIO46-LOG)
GND: 11.12, *C8.2, C1.1, C2.1, C3.1, C4.1, C5.1, C6.1, C7.-, C8.2, C9.1, C10.1, C11.1, C12.1, C13.1, C14.2, C15.1, C17.1, C18.1, C19.1, C20.2, C21.2, C22.1, CARD.6, EN1.5, EN2.5, I2S.2, IR.3, JOY.1, KB.4, M2.GND, M2.SCK, OLED.6, R5.1, R7.1, R8.1, R13.1, R17.1, R18.1, SD1.6 (VSS), SD1.S1, SD1.S2, SD1.S3, SD1.S4, SV4.1, SV4.2, SV7.10, U1.2 (VSS), U$1.GND1, U$1.GND2, U$1.GND3, U$1.GND4, UBS2.1, USB-C.A1/B12 (GND_2), USB-C.B1/A12 (GND)
I2C-SCL-ADC: 11.5, *C8.1, KB.2, R9.1, R11.1, U$1.9 (GPIO9-T9-SCL-FSPIHD)
I2C-SDA: 11.2, KB.1, R10.1, U$1.8 (GPIO8-T8_SDA)
MISO-SD: CARD.5, R21.1, SV4.5, U$1.21 (GPIO21)
MOSI-SD: CARD.3, R19.1, SV4.7, U$1.48 (SPICLK_N_GPIO48)
unnamed: AUDIO-OUT.1, M2.R, R-OUT.1
unnamed: AUDIO-OUT.3, L-OUT.1, M2.L
unnamed: OLED.5, R1.2
unnamed: OLED.4, R2.2
unnamed: OLED.3, R3.2
unnamed: R21.2, SD1.7 (DAT0(DO))
unnamed: 1.10, JOY.3, R6.1, R7.2, U$1.17 (GPIO17-TXD1_2)
unnamed: 11.1, J3.1, JOY.5, U$1.18 (GPIO18-RXD1_2)
unnamed: 11.10, J2.1, M2.LCK, U$1.14 (GPIO14-T14-FSPIDQS)
unnamed: 1.3, *R8.2, U$1.RST
unnamed: R20.2, SD1.2 (CD/DAT3(!CS!))
unnamed: 1.9, JOY.4, R4.1, R5.2, U$1.16 (GPIO16-TXD1_1)
unnamed: 11.9, J4.1, M2.DIN, U$1.13 (GPIO13-T13-FSPIQ)
unnamed: 11.8, J5.1, M2.BCK, U$1.12 (GPIO12-T12-FSPICLK)
unnamed: 1.7, U$1.7 (GPIO7-T7-ADC1_6)
unnamed: SV7.6, U$1.2 (ADC1_1-T2-GPIO2)
unnamed: 1.8, IR.1, R14.1, U$1.15 (GPIO15-T12-RXD1_1)
unnamed: D2.C, R8.2
unnamed: SV7.8, U$1.44 (RXD0-GPIO44)
unnamed: SV7.9, U$1.43 (TXD0-GPIO43)
unnamed: SV4.3, U$1.19 (USB_D-_GPIO19)
unnamed: SV4.4, U$1.20 (USB_D+_GPIO20)
unnamed: SV4.9, U$1.0 (BOOT-GPIO0)
unnamed: SV4.10, U$1.35 (MOSI-FSPID-GPIO35)
unnamed: SV4.11, U$1.36 (SCK-FSPICLK-GPIO36)
unnamed: SV4.12, U$1.37 (MISO-FSPIQ-GPIO37)
unnamed: 11.3, R12.1, U$1.3 (GPIO3-T3-JTAG)
unnamed: D1.C, R13.2
unnamed: CARD.1, J1.2
unnamed: R19.2, SD1.3 (CMD(DI))
unnamed: R16.2, SD1.5 (CLK(SCLK))
unnamed: U1.3 (IO2), UBS2.5, USB.2, USB-C.A6 (DP1), USB-C.B6 (DP2)
unnamed: U1.1 (IO1), UBS2.4, USB.1, USB-C.A7 (DN1), USB-C.B7 (DN2)
unnamed: I2S.3, J2.2
unnamed: R17.2, U1.4 (IO3), UBS2.2, USB-C.B5 (CC2)
unnamed: R18.2, U1.6 (IO4), UBS2.3, USB-C.A5 (CC1)
unnamed: I2S.6, J3.2
unnamed: I2S.5, J5.2
unnamed: I2S.4, J4.2
OLED-CLK: R1.1, SV7.1, U$1.38 (FSPIWP-LED-GPIO38)
OLED-CS: OLED.1, SV7.5, U$1.42 (MTMS-GPIO42)
OLED-DC: R3.1, SV7.3, U$1.40 (CLK2-MTDO-GPIO40)
OLED-MOSI: R2.1, SV7.2, U$1.39 (CLK3-MTCK-GPIO39)
OLED-RESET: OLED.2, SV7.4, U$1.41 (CKL1-MTDI-GPIO41)
SW1: 1.4, EN1.3, U$1.4 (GPIO4-T4-ADC1_3)
SW2: EN2.3, SV7.7, U$1.1 (ADC1_0-T1-GPIO1)

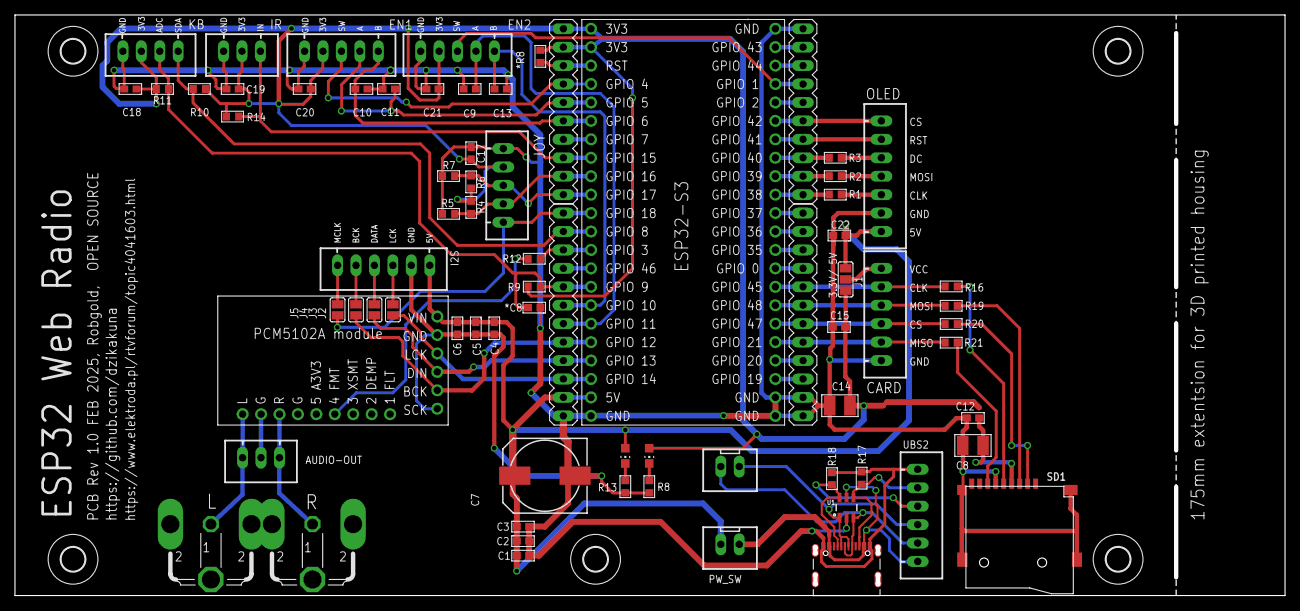
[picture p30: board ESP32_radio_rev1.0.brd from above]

Board: 2 copper layers, 175.0 x 80.0 mm, 78 parts (0 on the bottom side), 63 nets.

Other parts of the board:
H2, H3, H8: MOUNT-HOLE3.3; 3,3

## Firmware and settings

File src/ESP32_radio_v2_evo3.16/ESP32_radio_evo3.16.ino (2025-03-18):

// ESP32 Radio Evo3
// Source -> https://github.com/dzikakuna/ESP32_radio_evo3/tree/main/src/ESP32_radio_v2_evo3.15
// Based on project https://github.com/sarunia/ESP32_radio_player_v2


#include "Arduino.h"      // Standardowy nagłówek Arduino, który dostarcza podstawowe funkcje i definicje
#include "Audio.h"        // Biblioteka do obsługi funkcji związanych z dźwiękiem i audio
#include "SPI.h"          // Biblioteka do obsługi komunikacji SPI
#include "SD.h"           // Biblioteka do obsługi kart SD
#include "FS.h"           // Biblioteka do obsługi systemu plików
#include <U8g2lib.h>      // Biblioteka do obsługi wyświetlaczy
#include <ezButton.h>     // Biblioteka do obsługi enkodera z przyciskiem
#include <HTTPClient.h>   // Biblioteka do wykonywania żądań HTTP, umożliwia komunikację z serwerami przez protokół HTTP
#include <Ticker.h>       // Mechanizm tickera do odświeżania timera 1s, pomocny do cyklicznych akcji w pętli głównej
#include <WiFiManager.h>  // Biblioteka do zarządzania konfiguracją sieci WiFi, opis jak ustawić połączenie WiFi przy pierwszym uruchomieniu jest opisany tu: https://github.com/tzapu/WiFiManager
//#include <WiFi.h>
#include <EEPROM.h>
//#include <ArduinoJson.h>          // Biblioteka do parsowania i tworzenia danych w formacie JSON, użyteczna do pracy z API
#include <Time.h>  // Biblioteka do obsługi funkcji związanych z czasem, np. odczytu daty i godziny
#include <ESPAsyncWebServer.h>
#include <AsyncTCP.h>

// Only for i2c Keyboard 
// #include "Wire.h"
// #include "I2CKeyPad8x8.h"


#define softwareRev "v3.16"    // Wersja oprogramowania radia
#define hostname "ESP32-Radio" // Definicja nazwy hosta widoczna na zewnątrz

// definicja pinow czytnika karty SD
#define SD_CS 47    // Pin CS (Chip Select) dla karty SD wybierany jako interfejs SPI
#define SD_SCLK 45  // Pin SCK (Serial Clock) dla karty SD
#define SD_MISO 21  // Pin MISO (Master In Slave Out) dla karty SD
#define SD_MOSI 48  // pin MOSI (Master Out Slave In) dla karty SD

// Definicja pinow dla wyswietlacza OLED 
#define SPI_MOSI_OLED 39  // Pin MOSI (Master Out Slave In) dla interfejsu SPI OLED
#define SPI_MISO_OLED 0   // Pin MISO (Master In Slave Out) brak dla wyswietlacza OLED
#define SPI_SCK_OLED 38   // Pin SCK (Serial Clock) dla interfejsu SPI OLED
#define CS_OLED 42        // Pin CS (Chip Select) dla interfejsu OLED
#define DC_OLED 40        // Pin DC (Data/Command) dla interfejsu OLED
#define RESET_OLED 41     // Pin Reset dla interfejsu OLED

// Definicja pinow dla przetwornika PCM5102A
#define I2S_DOUT 13             // Podłączenie do pinu DIN na DAC
#define I2S_BCLK 12             // Podłączenie po pinu BCK na DAC
#define I2S_LRC 14              // Podłączenie do pinu LCK na DAC

#define SCREEN_WIDTH 256        // Szerokość ekranu w pikselach
#define SCREEN_HEIGHT 64        // Wysokość ekranu w pikselach

// Enkoder 1 - uzwyany dla odtwarzacza
#define CLK_PIN1 6              // Podłączenie z pinu 6 do CLK na enkoderze prawym
#define DT_PIN1 5               // Podłączenie z pinu 5 do DT na enkoderze prawym
#define SW_PIN1 4               // Podłączenie z pinu 4 do SW na enkoderze prawym (przycisk)

// Enkoder 2 - uzywany dla radia
#define CLK_PIN2 10             // Podłączenie z pinu 10 do CLK na enkoderze
#define DT_PIN2 11              // Podłączenie z pinu 11 do DT na enkoderze lewym
#define SW_PIN2 1               // Podłączenie z pinu 1 do SW na enkoderze lewym (przycisk)

// IR odbiornik podczerwieni 
#define recv_pin 15

#define MAX_STATIONS 99        // Maksymalna liczba stacji radiowych, które mogą być przechowywane w jednym banku
#define STATION_NAME_LENGTH 200  // Nazwa stacji wraz z bankiem i numerem stacji do wyświetlenia w pierwszej linii na ekranie
#define MAX_FILES 100           // Maksymalna liczba plików lub katalogów w tablicy directoriesz

#define STATIONS_URL1 "https://raw.githubusercontent.com/dzikakuna/ESP32_radio_streams/main/bank01.txt"   // Adres URL do pliku z listą stacji radiowych
#define STATIONS_URL2 "https://raw.githubusercontent.com/dzikakuna/ESP32_radio_streams/main/bank02.txt"   // Adres URL do pliku z listą stacji radiowych
#define STATIONS_URL3 "https://raw.githubusercontent.com/dzikakuna/ESP32_radio_streams/main/bank03.txt"   // Adres URL do pliku z listą stacji radiowych
#define STATIONS_URL4 "https://raw.githubusercontent.com/dzikakuna/ESP32_radio_streams/main/bank04.txt"   // Adres URL do pliku z listą stacji radiowych
#define STATIONS_URL5 "https://raw.githubusercontent.com/dzikakuna/ESP32_radio_streams/main/bank05.txt"   // Adres URL do pliku z listą stacji radiowych
#define STATIONS_URL6 "https://raw.githubusercontent.com/dzikakuna/ESP32_radio_streams/main/bank06.txt"   // Adres URL do pliku z listą stacji radiowych
#define STATIONS_URL7 "https://raw.githubusercontent.com/dzikakuna/ESP32_radio_streams/main/bank07.txt"   // Adres URL do pliku z listą stacji radiowych
#define STATIONS_URL8 "https://raw.githubusercontent.com/dzikakuna/ESP32_radio_streams/main/bank08.txt"   // Adres URL do pliku z listą stacji radiowych
#define STATIONS_URL9 "https://raw.githubusercontent.com/dzikakuna/ESP32_radio_streams/main/bank09.txt"   // Adres URL do pliku z listą stacji radiowych
#define STATIONS_URL10 "https://raw.githubusercontent.com/dzikakuna/ESP32_radio_streams/main/bank10.txt"  // Adres URL do pliku z listą stacji radiowych
#define STATIONS_URL11 "https://raw.githubusercontent.com/dzikakuna/ESP32_radio_streams/main/bank11.txt"  // Adres URL do pliku z listą stacji radiowych
#define STATIONS_URL12 "https://raw.githubusercontent.com/dzikakuna/ESP32_radio_streams/main/bank12.txt"  // Adres URL do pliku z listą stacji radiowych
#define STATIONS_URL13 "https://raw.githubusercontent.com/dzikakuna/ESP32_radio_streams/main/bank13.txt"  // Adres URL do pliku z listą stacji radiowych
#define STATIONS_URL14 "https://raw.githubusercontent.com/dzikakuna/ESP32_radio_streams/main/bank14.txt"  // Adres URL do pliku z listą stacji radiowych
#define STATIONS_URL15 "https://raw.githubusercontent.com/dzikakuna/ESP32_radio_streams/main/bank15.txt"  // Adres URL do pliku z listą stacji radiowych
#define STATIONS_URL16 "https://raw.githubusercontent.com/dzikakuna/ESP32_radio_streams/main/bank16.txt"  // Adres URL do pliku z listą stacji radiowych


// ----------- PILOT IR ----------- //
// Przypisanie przycisków i adresu pilota w standardzie NEC 
// pierwszy bajt adres, drugi komenda (B914 - adres B9 komenda 14)

#define rcCmdVolumeUp   0xB914  // Głosnosc +
#define rcCmdVolumeDown 0xB915  // Głośnosc -
#define rcCmdArrowRight 0xB90B  // strzałka w prawo - nastepna stacja
#define rcCmdArrowLeft  0xB90A  // strzałka w lewo - poprzednia stacja  
#define rcCmdArrowUp    0xB987  // strzałka w góre - lista stacji krok do gory
#define rcCmdArrowDown  0xB986  // strzałka w dół - lista stacj krok na dół
#define rcCmdBack       0xB985  // Przycisk powrotu
#define rcCmdOk         0xB90E  // Przycisk Ent - zatwierdzenie stacji
#define rcCmdSrc        0xB913  // Przełączanie źródła radio, odtwarzacz
#define rcCmdMute       0xB916  // Wyciszenie dzwieku
#define rcCmdAud        0xB917  // Equalizer dzwieku
#define rcCmdDirect     0xB90F  // Janość ekranu, dwa tryby 1/16 lub pełna janość     
#define rcCmdBankMinus  0xB90C  // Wysweitla wybór banku
#define rcCmdBankPlus   0xB90D  // Wysweitla wybór banku
#define rcCmdRed        0xB988  // Przełacza ładowanie banku kartaSD - serwer GitHub w menu bank
#define rcCmdGreen      0xB992  // VU wyłaczony, VU tryb 1, VU tryb 2, zegar
#define rcCmdKey0       0xB900  // Przycisk "0"
#define rcCmdKey1       0xB901  // Przycisk "1"
#define rcCmdKey2       0xB902  // Przycisk "2"
#define rcCmdKey3       0xB903  // Przycisk "3"
#define rcCmdKey4       0xB904  // Przycisk "4"
#define rcCmdKey5       0xB905  // Przycisk "5"
#define rcCmdKey6       0xB906  // Przycisk "6"
#define rcCmdKey7       0xB907  // Przycisk "7"
#define rcCmdKey8       0xB908  // Przycisk "8"
#define rcCmdKey9       0xB909  // Przycisk "9"

bool cmdVolumeUp = false;    // Flaga Głosnosc +
bool cmdVolumeDown = false;  // Flaga  Głośnosc -
bool cmdArrowRight = false;// Flaga strzałka w prawo - nastepna stacja
bool cmdArrowLeft = false;   // Flaga strzałka w lewo - poprzednia stacja  
bool cmdArrowUp = false;     // Flaga strzałka w góre - lista stacji krok do gory
bool cmdArrowDown = false;   // Flaga strzałka w dół - lista stacj krok na dół
bool cmdBack = false;        // Flaga Przycisk powrotu
bool cmdOk = false;          // Flaga Przycisk Ent - zatwierdzenie stacji
bool cmdSrc = false;         // Flaga Przełączanie źródła radio, odtwarzacz
bool cmdMute = false;        // Flaga Wyciszenie dzwieku
bool cmdAud = false;         // Flaga Equalizer dzwieku
bool cmdDirect = false;      // Flaga Janość ekranu, dwa tryby 1/16 lub pełna janość     
bool cmdBankMinus = false;   // Flaga Wysweitla wybór banku
bool cmdBankPlus = false;    // Flaga Wysweitla wybór banku
bool cmdBankNetUpdate = false;         // Flaga Przełacza ładowanie banku kartaSD - serwer GitHub w menu bank
bool cmdDisplayMode = false;       // Flaga VU wyłaczony, VU tryb 1, VU tryb 2, zegar
bool cmdKey0 = false;        // Flaga Przycisk "0"
bool cmdKey1 = false;        // Flaga Przycisk "1"
bool cmdKey2 = false;        // Flaga Przycisk "2"
bool cmdKey3 = false;        // Flaga Przycisk "3"
bool cmdKey4 = false;        // Flaga Przycisk "4"
bool cmdKey5 = false;        // Flaga Przycisk "5"
bool cmdKey6 = false;        // Flaga Przycisk "6"
bool cmdKey7 = false;        // Flaga Przycisk "7"
bool cmdKey8 = false;        // Flaga Przycisk "8"
bool cmdKey9 = false;        // Flaga Przycisk "9


int currentSelection = 0;       // Numer aktualnego wyboru na ekranie OLED
int firstVisibleLine = 0;       // Numer pierwszej widocznej linii na ekranie OLED
uint8_t station_nr = 0;         // Numer aktualnie wybranej stacji radiowej z listy
int stationFromBuffer = 0;      // Numer stacji radiowej przechowywanej w buforze do przywrocenia na ekran po bezczynności
uint8_t bank_nr;                // Numer aktualnie wybranego banku stacji z listy
uint8_t previous_bank_nr = 0;   // Numer banku przed wejsciem do menu zmiany banku
int bankFromBuffer = 0;         // Numer aktualnie wybranego banku stacji z listy do przywrócenia na ekran po bezczynności
uint8_t screenRefreshCount = 0; // odświezeanie ekranu dla stajci bez statoin string
uint8_t screenRefreshCountValue = 6; // Zmiena okreslajaca po ilu petlach nastapia ponowne odświezeanie ekranu OLED dla stajcji

int CLK_state1;                        // Aktualny stan CLK enkodera prawego
int prev_CLK_state1;                   // Poprzedni stan CLK enkodera prawego
int CLK_state2;                        // Aktualny stan CLK enkodera lewego
int prev_CLK_state2;                   // Poprzedni stan CLK enkodera lewego
//int counter = 0;                       // Licznik dla przycisków
int stationsCount = 0;                 // Aktualna liczba przechowywanych stacji w tablicy
int directoryCount = 0;                // Licznik katalogów
int fileIndex = 0;                     // Numer aktualnie wybranego pliku audio ze wskazanego folderu
int fileFromBuffer = 0;                // Numer aktualnie wybranego pliku do przywrócenia na ekran po bezczynności
int folderIndex = 0;                   // Numer aktualnie wybranego folderu podczas przełączenia do odtwarzania z karty SD
int folderFromBuffer = 0;              // Numer aktualnie wybranego folderu do przywrócenia na ekran po bezczynności
int totalFilesInFolder = 0;            // Zmienna przechowująca łączną liczbę plików w folderze
uint8_t volumeValue = 10;                  // Wartość głośności, domyślnie ustawiona na 10
uint8_t volumeBufferValue = 0;             // Wartość głośności, domyślnie ustawiona na 10
//int cycle = 0;                         // Numer cyklu do danych pogodowych wyświetlanych w trzech rzutach co 10 sekund
int maxVisibleLines = 4;               // Maksymalna liczba widocznych linii na ekranie OLED
int bitrateStringInt = 0;              // Deklaracja zmiennej do konwersji Bitrate string na wartosc Int aby podzelic bitrate przez 1000
int buttonLongPressTime1 = 2000;       // Czas reakcji na długie nacisniecie enkoder 1
int buttonLongPressTime2 = 2000;       // Czas reakcji na długie nacisniecie enkoder 2
int buttonShortPressTime2 = 500;       // Czas rekacjinna krótkie nacisniecie enkodera 2
int buttonSuperLongPressTime2 = 4000;  // Czas reakcji na super długie nacisniecie enkoder 2

// ---- Auto dimmer / auto przyciemnianie wyswietlacza ---- //
uint8_t displayDimmerTimeCounter = 0;  // Zmienna inkrementowana w przerwaniu timera2 do przycimniania wyswietlacz
uint8_t dimmerDisplayBrightness = 4;   // Wartość przyciemnienia wyswietlacza po czasie niekatywnosci
uint8_t displayBrightness = 15;        // Domyślna maksymalna janość wyswietlacza
uint16_t displayAutoDimmerTime = 10;   // Czas po jakim nastąpi przyciemninie wyswietlacza, liczony w sekundach
bool displayAutoDimmerOn = true;       // Automatyczne przyciemnianie wyswietlacza, domyślnie włączone

uint8_t displayMode = 0;               // Tryb wyswietlacza 0-displayRadio / 1-Zegar

// ---- Equalzier ---- //
int8_t toneLowValue = 0;               // Wartosc filtra dla tonow niskich
int8_t toneMidValue = 0;               // Wartosc flitra dla tonow srednich
int8_t toneHiValue = 0;                // Wartość filtra dla tonow wysokich
uint8_t toneSelect = 1;                // Zmienna okreslająca, który filtr equalizera regulujemy
bool equalizerMenuEnable = false;      // Flaga wyswietlania menu Equalizera


uint8_t max_connection = 10;
uint8_t rcPage = 0;

uint8_t rcInputDigit1 = 0xFF;      // Pierwsza cyfra w przy wprowadzaniu numeru stacji z pilota
uint8_t rcInputDigit2 = 0xFF;      // Druga cyfra w przy wprowadzaniu numeru stacji z pilota


// ---- Config ---- // - prototype function for config storage
uint8_t configArray[16] = { 0 };

//const int maxVisibleLines = 5;  // Maksymalna liczba widocznych linii na ekranie OLED
bool encoderButton1 = false;      // Flaga określająca, czy przycisk enkodera 1 został wciśnięty
bool encoderButton2 = false;      // Flaga określająca, czy przycisk enkodera 2 został wciśnięty
bool encoderFunctionOrder = true;// Flaga okreslająca kolejność funkcji enkodera 2
bool fileEnd = false;             // Flaga sygnalizująca koniec odtwarzania pliku audio
bool displayActive = false;       // Flaga określająca, czy wyświetlacz jest aktywny
bool isPlaying = false;           // Flaga określająca, czy obecnie trwa odtwarzanie
bool mp3 = false;                 // Flaga określająca, czy aktualny plik audio jest w formacie MP3
bool flac = false;                // Flaga określająca, czy aktualny plik audio jest w formacie FLAC
bool aac = false;                 // Flaga określająca, czy aktualny plik audio jest w formacie AAC
bool vorbis = false;                 // Flaga określająca, czy aktualny plik audio jest w formacie VORBIS
bool id3tag = false;              // Flaga określająca, czy plik audio posiada dane ID3
bool timeDisplay = true;          // Flaga określająca kiedy pokazać czas na wyświetlaczu, domyślnie od razu po starcie
bool listedStations = false;      // Flaga określająca czy na ekranie jest pokazana lista stacji do wyboru
bool menuEnable = false;          // Flaga określająca czy na ekranie można wyświetlić menu
bool bankMenuEnable = false;      // Flaga określająca czy na ekranie jest wyświetlone menu wyboru banku
bool bitratePresent = false;      // Flaga określająca, czy na serial terminalu pojawiła się informacja o bitrate - jako ostatnia dana spływajaca z info
bool bankNetworkUpdate = false;   // Flaga wyboru aktualizacji banku z sieci lub karty SD - True aktulizacja z NETu
bool bank1NetworkUpdate = false;  // Flaga wyboru aktualizacji banku z sieci lub karty SD - True aktulizacja z NETu
bool bank2NetworkUpdate = false;  // Flaga wyboru aktualizacji banku z sieci lub karty SD
bool volumeMute = false;          // Flaga okreslająca stan funkcji wyciszczenia - Mute


bool volumeSet = false;           // Flaga wejscia menu regulacji głosnosci na enkoderze 2
bool vuMeterOn = true;            // Flaga właczajaca wskazniki VU
bool vuMeterMode = false;         // tryb rysowania vuMeter
bool action3Taken = false;        // Flaga Akcji 3 - załaczenia VU
bool updateTimeAtStart = false;    // AKtualizacja czasu po pierwszym uruchomieniu
bool ActionNeedUpdateTime = false; // Zmiena okresaljaca dla displayRadio potrzebe odczytu aktulizacji czasu
bool debugAudioBuffor = false;     // Wyswietlanie bufora Audio
bool screenRefresh = false;         // Dodatkowe odswiezanie ekranu, właczone przy pierwszym uruchomieniu
bool audioShowStreamtitleRefresh = false;
bool audioInfoRefresh = false;
bool vuMeterOnFlacStations = true;
bool noSDcard = false;              // flaga ustawiana przy braku wykrycia karty SD
//bool noSDcardAlert = false;//true;          // Informacja o braku karty na wyswietlaczu, ustawienie na false powoduje, ze radio nie będzie jej wyswietlać
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
void loop() 
{
  runTime1 = esp_timer_get_time();
  wifiManager.process();  // WiFi manager
  audio.loop();           // Wykonuje główną pętlę dla obiektu audio (np. odtwarzanie dźwięku, obsługa audio)
  button1.loop();         // Wykonuje pętlę dla obiektu button1 (sprawdza stan przycisku z enkodera 1)
  button2.loop();         // Wykonuje pętlę dla obiektu button2 (sprawdza stan przycisku z enkodera 2)
  handleButtons();        // Wywołuje funkcję obsługującą przyciski i wykonuje odpowiednie akcje (np. zmiana opcji, wejście do menu)
  //webServer();            // Uruchamiamy Web serwer
  vTaskDelay(1);          // Krótkie opóźnienie, oddaje czas procesora innym zadaniom

  /* -------------- KLAWIATURA --------------*/
  /* Odczyt stanu klawiatura ADC pod GPIO 9 */
  
//  if (millis() - keyboardLastSampleTime >= keyboardSampleDelay) // Sprawdzenie ADC - klawiatury 
//  {
//    keyboardLastSampleTime = millis();
//    handleKeyboard();
//  }
  
  if (displayActive == true) {displayDimmer(0);}  
  
  // Obsługa enkodera 1
  handleEncoder1(); 
  
  // Obsługa enkodera 2
  if (encoderFunctionOrder == 0) { handleEncoder2VolumeStationsClick(); } 
  else if (encoderFunctionOrder == 1) { handleEncoder2StationsVolumeClick(); }

  
  
 /*---------------------  FUNKCJA BACK / POWROTU ze wszystkich opcji Menu, Ustawien, itd ---------------------*/

  if (displayActive && (millis() - displayStartTime >= displayTimeout))  // Przywracanie poprzedniej zawartości ekranu po 6 sekundach
  {
    Serial.print("rcInputDigitsMenuEnable: ");
    Serial.println(rcInputDigitsMenuEnable);

    Serial.print("Station nr: ");
    Serial.println(station_nr);
    
    Serial.print("Bank nr: ");
    Serial.println(bank_nr);

    //-- Nie zmieniamy automatycznie Banku, funkcja wyłaczona --
    // Sprawdzamy czy nie musimy zmienic banku lub stacji   
    /*
    if ((rcInputDigitsMenuEnable == true) && (bank_nr != previous_bank_nr)) 
    {
      station_nr = 1;
      fetchStationsFromServer();
      bankMenuEnable = false;
      changeStation(); 
    }
    */
    if (volumeBufferValue != volumeValue)
    {
      saveVolumeOnSD();
      volumeBufferValue = volumeValue;
    }

    if ((rcInputDigitsMenuEnable == true) && (station_nr != stationFromBuffer)) // Jezeli nastapiła zmiana numeru stacji to wczytujemy nową stacje    
    {
     changeStation(); 
    }

    displayDimmer(0);
    displayActive = false;
    timeDisplay = true;
    listedStations = false;
    menuEnable = false;
    volumeSet = false;
    bankMenuEnable = false;
    bankNetworkUpdate = false;
    equalizerMenuEnable = false;
    rcInputDigitsMenuEnable = false;
    rcInputDigit1 = 0xFF; // czyscimy cyfre 1, flaga pustej zmiennej to FF
    rcInputDigit2 = 0xFF; // czyscimy cyfre 2, flaga pustej zmiennej to FF
    currentOption = INTERNET_RADIO;

    station_nr = stationFromBuffer;
    bank_nr = previous_bank_nr;
    
    displayRadio();
    u8g2.sendBuffer();
  }

 

/*
  if (updateTimeAtStart = false)  // aktualizujemy zegar i wyswietlacz ale tylko raz przy starcie zanim wejdziemy do funkcji millis odswiezania scrollera
  {
    displayRadio();
    updateTimer();
    updateTimeAtStart = true;
  }
*/

 /*---------------------  PILOT IR - NEC  ---------------------*/ 

  if (bit_count == 32) // sprawdzamy czy odczytalismy w przerwaniu pełne 32 bity kodu IR NEC
  {
    if (ir_code != 0) // sprawdzamy czy zmienna ir_code nie jest równa 0
    {
      
      detachInterrupt(recv_pin); // rozpinay przerwanie
      Serial.print("Kod NEC OK:");
      Serial.print(ir_code, HEX);
      ir_code = reverse_bits(ir_code,32);     // rotacja bitów zmiana z LSB-MSB na MSB-LSB
      Serial.print("  MSB-LSB: ");
      Serial.print(ir_code, HEX);
    
      uint8_t CMD = (ir_code >> 16) & 0xFF; // Drugi bajt (inwersja adresu)
      uint8_t ADDR = ir_code & 0xFF;        // Czwarty bajt (inwersja komendy)
      
      Serial.print("  ADR:");
      Serial.print(ADDR, HEX);
      Serial.print(" CMD:");
      Serial.println(CMD, HEX);
      ir_code = ADDR << 8 | CMD;      // Łączymy ADDR i CMD w jedną zmienną 0xDDRCMD

      Serial.print("debug-- puls 9ms:");
      Serial.print(pulse_duration_9ms);
      Serial.print("  4.5ms:");
      Serial.print(pulse_duration_4_5ms);
      Serial.print("  1690us:");
      Serial.print(pulse_duration_1690us);
      Serial.print("  690us:");
      Serial.println(pulse_duration_560us);
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

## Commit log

2025-01-10 ESP32 Radio evo3.1
2025-01-11 Case/Housing STL files update
    [Front panel v1.23e-long.3mf, Front panel v1.23e-long.skp, Front panel v1.23e-long.stl]
2025-01-12 Update - fonts, stl files for 3d print
    [Cover_v1_profil_1.8_long.3mf, Cover_v1_profil_1.8_long.stl, Front panel v1.23e-long.3mf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]
2025-03-01 PCB Gerbers for review
    [ESP32_radio_rev1.0.GBL, ESP32_radio_rev1.0.GBO, ESP32_radio_rev1.0.GBS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]
2025-03-02 Schematic & PCB update
    [ESP32_radio_rev1.0.brd, ESP32_radio_rev1.0.sch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]
2025-03-15 Housing backplate update
    [Back_panel_v1.01c-long.3mf, Back_panel_v1.01c-long.skp, Back_panel_v1.04c-long.3mf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]
2025-03-18 Update Arduino and Platformio
    [partitions.csv]
2025-04-19 Update 3.17.65
    New one menu button, new bank editor v1.05.
2025-06-07 Update 3.18.04
    New Scroller Formater, 1250 to UTF8 in Station String formater add.
    [partitions.csv]
2026-05-09 Update 3.20.14
    ESP32 Core: 3.3.8 + "FLAC" lwip libs recompiled based on IDF 5.5.4, Arduino: 2.3.6
2026-10-18 Update to new ESP IDF
    3.22.00
    ESP32 Core: 3.3.12 based on ESP-IDF 5.5.5
    liblwip.a, libesp_netif.a, "FLAC" libs: recompiled on ESP-IDF 5.5.5
    Arduino 2.3.10
    Audio lib: 4.0.0t commits 28.09.2026
    New audio_event for new Audio library introduced
    New mode - Spectrum analyzer full screen
    Centered mode - bottm Vu meter replaced by spectrum analyzer

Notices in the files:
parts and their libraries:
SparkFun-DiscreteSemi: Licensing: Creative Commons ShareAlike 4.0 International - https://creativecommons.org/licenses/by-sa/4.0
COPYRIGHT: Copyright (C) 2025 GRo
